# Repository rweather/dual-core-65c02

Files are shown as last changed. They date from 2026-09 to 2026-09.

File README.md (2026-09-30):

Dual Core 65C02 Computer
========================

This repository contains schematics, documentation, and program code for my
dual core 65C02 computer.  The computer has two 65C02 microprocessors,
sharing a common memory and I/O bus for symmetric multiprocessing (SMP),
8-bit style.

Here is what it looks like on a PCB.  The two large 40-pin chips at the
top are the CPU's.

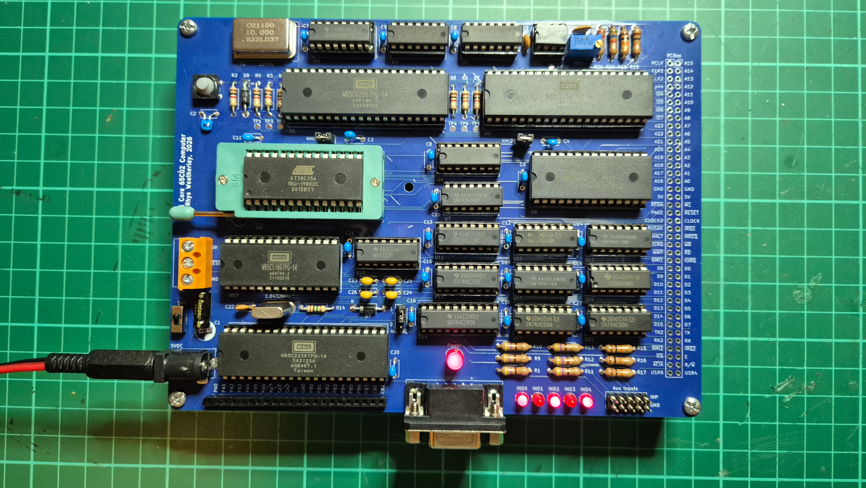
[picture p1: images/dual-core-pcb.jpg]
PCB Layout


If you would like to build your own, I have
[shared the design on PCBway](https://www.pcbway.com/project/shareproject/Dual_Core_65C02_Computer_47504aca.html).  Or contact me at the e-mail address
below and I might still have some spare PCB's I can mail out.

## How did this happen?

Steve Wozniak's design of the Apple II avoided video snow by alternating
access to main memory between the 6502 CPU and the video system.  The two
systems cannot collide and thus cannot create snow.

I asked myself, "Could I do that with two CPU's?" and an obsession was born.

## How does it work?

The W65C02S CPU from Western Digital simplifies things.  The BE
(bus enable) pin can be pulled low to take the CPU completely off the bus
temporarily.  By alternating the bus enables, each CPU can be given
access to memory and I/O in turn.

It would theoretically be possible to do this with the original 6502
microprocessor, but extra bus transceivers would be required as
the original 6502 does not have a BE pin.  The Apple II design
includes bus transceivers for exactly this purpose.

The main 12MHz crystal oscillator is divided down into a number of
component clock signals:

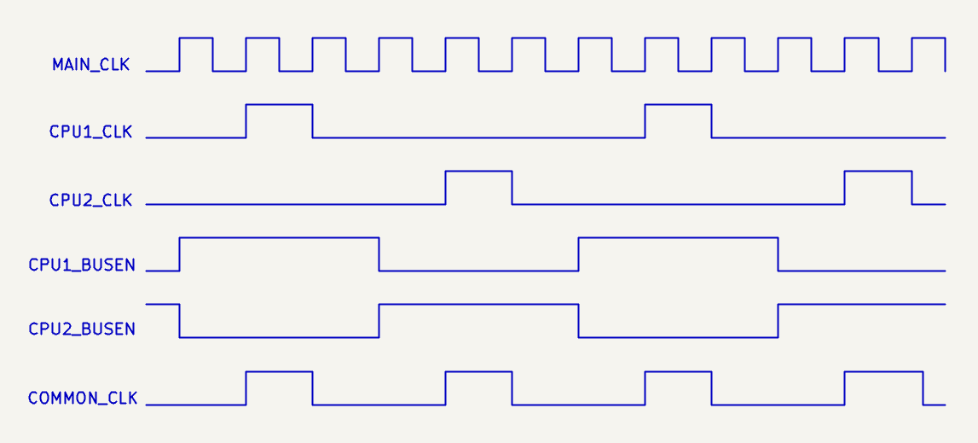
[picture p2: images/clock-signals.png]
Clock Signals


<table border="1">
<tr><td><b>Signal</b></td><td><b>Description</b></td></tr>
<tr><td>CPU1 CLK</td><td>2MHz clock for CPU1</td></tr>
<tr><td>CPU2 CLK</td><td>2MHz clock for CPU2</td></tr>
<tr><td>CPU1 BUSEN</td><td>2MHz bus enable for CPU1</td></tr>
<tr><td>CPU2 BUSEN</td><td>2MHz bus enable for CPU2</td></tr>
<tr><td>COMMON CLK</td><td>4MHz common clock for memory and I/O</td></tr>
</table>

## Memory map

<table border="1">
<tr><td><b>Address Range</b></td><td><b>Description</b></td></tr>
<tr><td>$0000 - $00FF</td><td>Zero page for CPU 1</td></tr>
<tr><td>$0100 - $01FF</td><td>Stack for CPU 1</td></tr>
<tr><td>$0200 - $02FF</td><td>Zero page for CPU 2</td></tr>
<tr><td>$0300 - $03FF</td><td>Stack for CPU 2</td></tr>
<tr><td>$0400 - $7FFF</td><td>Shared RAM (31K)</td></tr>
<tr><td>$8000 - $81FF</td><td>Main board I/O</td></tr>
<tr><td>$8200 - $83FF</td><td>Versatile Interface Adapter (VIA)</td></tr>
<tr><td>$8400 - $84FF</td><td>Asynchronous Communications Interface Adapter (ACIA)</td></tr>
<tr><td>$8600 - $87FF</td><td>RCbus I/O address space</td></tr>
<tr><td>$8800 - $8FFF</td><td>Spare I/O address space</td></tr>
<tr><td>$9000 - $BFFF</td><td>Unused memory space (12K)</td></tr>
<tr><td>$C000 - $FFFF</td><td>CPU-specific ROM (16K)</td></tr>
</table>

Address ranges $0000 - $01FF and $0200 - $03FF are swapped in CPU2 so that
CPU2 sees its zero page and stack starting at $0000 and sees CPU1's
zero page and stack starting at $0200.  This keeps the zero pages and
stacks separate.

The design uses a 32K EEPROM, divided into two 16K halves.  CPU1 sees
the first half of the ROM and CPU2 sees the second half of the ROM.
Thus, different programs can run on each CPU, or the same program.
It is up to the programmer.  This repository contains a minimal
[BIOS](src/common/bios.s) for initializing and accessing the hardware.

The main board decodes 8 I/O device address ranges between $8000 and $8FFF,
each consisting of 512 bytes ($0200 hex).  Four of these are used for
purposes on the main board.  The others are spare for expansion boards.

The 12K of unused memory space can be used for bank-switched RAM, video
memory, cartridge ROM's, or anything you want.

## Mutual exclusion

In any multi-core system, some method is required to synchronise access to
memory and I/O across the cores.  The 65C02 takes multiple clock cycles to
perform a read-modify-write instruction like "INC" or "DEC".  The other core
could get in the middle of that and mess things up.

According to the W65C02S datasheet, the ML pin can be used to co-ordinate
bus accesses when read-modify-write instructions are being performed.
I experimented with a method to "stretch" the bus enable signals to
delay the other CPU while the current one was performing a read-modify-write.
But I wasn't able to make it stable.

Instead, I use two flip-flops and some I/O pins to provide mutual exclusion.
In Logisim, it looks like this:

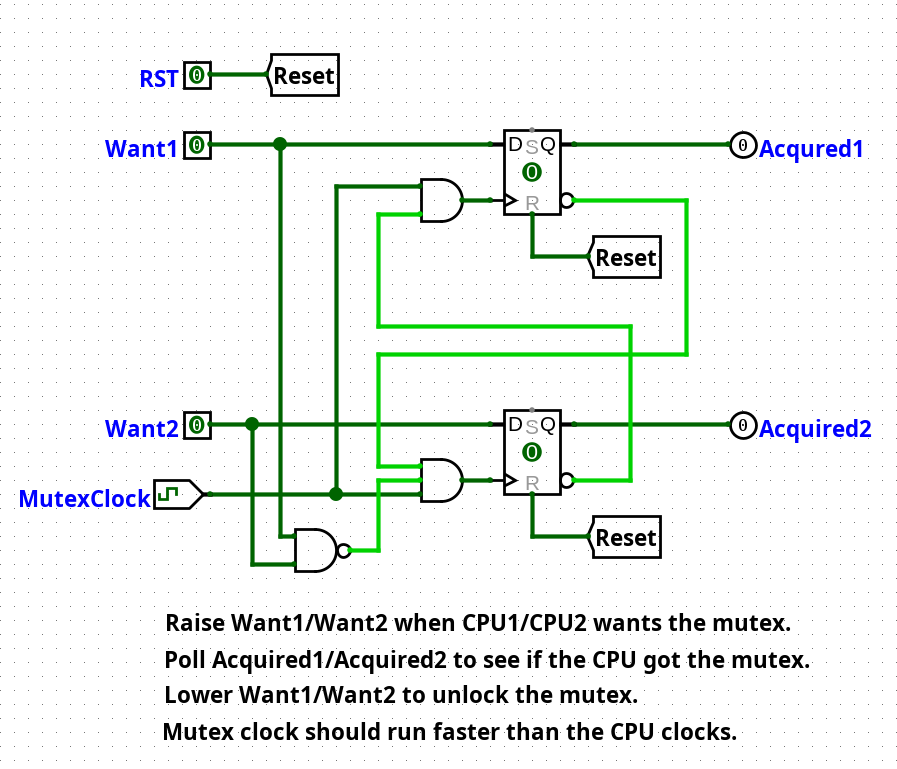
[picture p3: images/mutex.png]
Mutual exclusion


When CPU1 wants the mutex, it raises the Want1 pin (address $8107, bit 0) and
then polls the Acquired1 signal (address $8080, bit 7).  Once the acquired
signal goes high, CPU1 has the mutex.  To release the mutex, lower the
Want1 pin.

CPU2 does the same thing with Want2 (address $8106, bit 0) and
Acquired2 (address $8080, bit 6).

The mutex is "fair" in the sense that when one CPU lowers its Want pin,
the other CPU is guaranteed to immediately get the mutex if it had
previously raised its Want pin.  It is impossible for one CPU to
hog the mutex, except by forgetting to unlock it.

The [BIOS](src/common/bios.s) provides the subroutines `mutex_lock`,
`mutex_unlock`, and `mutex_try_lock` to make things easier for the
programmer.  The implementation is different for each CPU.

## System millisecond tick timer

There is a 555 timer in the circuit that delivers a 1000Hz signal to the
NMI pins on each of the CPU's.  A potentiometer allows the frequency to
be dialed in precisely.

The default NMI handler in the BIOS increments a 24-bit millisecond
tick counter which wraps around after 4 hours and 39 minutes.
Call the `systick` subroutine to fetch the value of the tick counter
safely into the Y:X:A register triple.

NMI can interfere with foreground code and regular IRQ handlers,
which may affect timing-critical code.  There are jumpers in the circuit
that allow the 555 to be disconnected from one or both of the CPU's.

## Schematic and other technical information

* [PDF of the schematic](schematics/DualCore6502Whole/PDF/DualCore6502Whole.pdf)
* [Gerbers for the PCB](schematics/DualCore6502Whole/Gerber)
* [Parts list](doc/parts-list.md)

## What can't it do?

DMA is not currently supported.  Pausing the clocks and bus enables to allow
external access to the bus is complicated.  Too complicated for my feeble brain.
Maybe in the next version.

In theory the W65C02S can go up to 14MHz.  While SRAM that is faster than
70ns access time is possible, AT28C256 EEPROM chips form are typically 150ns.
In practice, this limits the maximum memory speed to about 4MHz.
AT27C256 EEPROM's can go down to 45ns but they are not pin-compatible and
that still only gets us to 8MHz or so.  An alternative memory design with
wait states may allow pushing the performance further.  Once again,
my feeble brain isn't up to the task.

Could we have more CPU's?  Four?  Eight?  In theory, yes.  But memory
access times limit things.  The speed of the individual CPU's would need to be
reduced to 1MHz to allow four on the bus, executing one after another.
The effective speed of the system would remain at 4MHz.  An alternate design
might give each CPU its own fast SRAM, with wait states for access to
common RAM, ROM, and I/O.

## TODO

* Machine monitor for loading programs into RAM via the serial port and
debugging them (partially done).
* Devise a multi-core operating system to showcase the capabilities.

## License

Distributed under the terms of the MIT license.

## Contact

For more information on this code, to report bugs, or to suggest
improvements, please contact the author Rhys Weatherley via
[email](mailto:rhys.weatherley@gmail.com).

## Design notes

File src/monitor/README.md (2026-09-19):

This directory contains a machine monitor for the Dual Core 65C02 Computer.

The name of the monitor is "Maggot MON", which is the name I used for my
replacement machine monitor projects for the Dick Smith Cat in the 1980's.
I was 15 years old!

Maggot MON has evolved over the years into a replacement for the
Apple II F8 ROM for use with homebrew 6502 computers.  Now with ANSI
colour codes over a TTY, support for lower case, improved assembler and
disassembler, and so on.

On a dual core system, the monitor runs in CPU1.

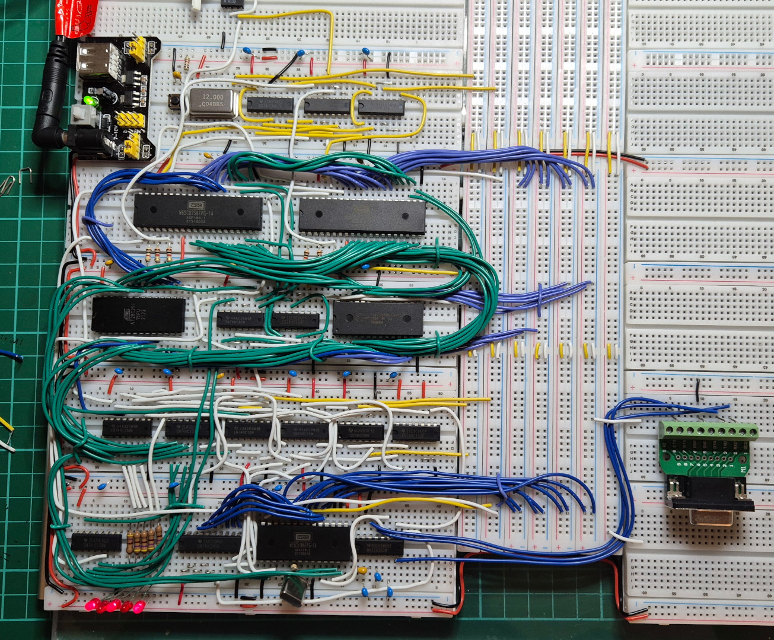
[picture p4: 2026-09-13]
images/dual-core-breadboard.jpg

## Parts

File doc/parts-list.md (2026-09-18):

Parts list for Dual Core 65C02
==============================

## Integrated Circuits

* 2 x W65C02S 8-bit microprocessor
* 1 x W65C22N versatile interface adapter (VIA)
* 1 x W65C51N asynchronous communications interface adapter (ACIA)
* 1 x 62256 32K x 8 static RAM, 70ns or better access time
* 1 x 28C256 32K x 8 EEPROM, 150ns or better access time
* 1 x MAX232 RS-232 line driver
* 1 x 7555 CMOS timer
* 3 x 74HC00 quad 2-input NAND gate
* 1 x 74HC02 quad 2-input NOR gate
* 1 x 74HC08 quad 2-input AND gate
* 1 x 74HC10 triple 3-input NAND gate
* 1 x 74HC32 quad 2-input OR gate
* 1 x 74HC74 dual D flip-flop
* 1 x 74HC86 quad 2-input XOR gate
* 2 x 74HC138 1 of 8 decoder
* 1 x 74HC245 8-bit bus transceiver
* 1 x 74HC259 8-bit addressable latch
* 1 x 74HC4017 decade counter

## Resistors

* 6 x 470R resistor
* 7 x 1K resistor
* 1 x 2K2 resistor
* 1 x 5K6 resistor
* 5 x 10K resistor
* 1 x 1M resistor
* 1 x 10K trimpot

Note: All resistors should be rated for at least 5% tolerance and 1/4W.

## Capacitors

* 1 x 100uF electroltic capacitor, min 10V rating
* 4 x 1uF ceramic or monolithic capacitor
* 22 x 100nF ceramic or monolithic capacitor
* 1 x 10nF ceramic or monolithic capacitor
* 1 x 20pF ceramic capacitor

## Diodes and LED's

* 2 x 1N5819 Schottky diodes or equivalent
* 1 x 5mm LED
* 5 x 3mm LED

Note: The current-limiting resistors for the LED's are specified as 470R
which is suitable for standard 10mA to 20mA LED's.  Adjust the value of the
current limiting resistors for other LED's.

## Sockets, Recommended

* 3 x 40-pin DIP socket (2 x W65C02S, 1 x W65C22N)
* 2 x 28-pin DIP socket (1 x 62256, 1 x W65C51N)
* 1 x 28-pin ZIF socket (1 x 28C256)

## Sockets, Optional

* 1 x 8-pin DIP socket
* 9 x 14-pin DIP socket
* 5 x 16-pin DIP socket
* 1 x 20-pin DIP socket

## Connectors and Headers

* 1 x DC barrel jack
* 1 x DSUB 9-pin RS-232 connector female
* 1 x 3-pin Phoenix connector or 3-pin 5.08mm pitch screw terminals
* 1 x 3-pin 2.54mm terminal pin header
* 2 x 2-pin 2.54mm terminal pin header
* 1 x 10-pin 2.54mm terminal pin header, 5x2 configuration
* 1 x 22-pin 2.54mm terminal pin socket
* 1 x 80-pin 2.54mm terminal pin socket, 40x2 configuration
* 8 x 2-pin 2.54mm jumper (NMI1, NMI2, VIA IRQ, and 5 Aux Inputs)

## Other

* 1 x 12MHz DIP-14 crystal oscillator
* 1 x 1.8432MHz crystal
* 1 x 3-pin 2.54mm pitch slider switch for power
* 1 x 6mm momentary pushbutton for reset
* 1 x PCB

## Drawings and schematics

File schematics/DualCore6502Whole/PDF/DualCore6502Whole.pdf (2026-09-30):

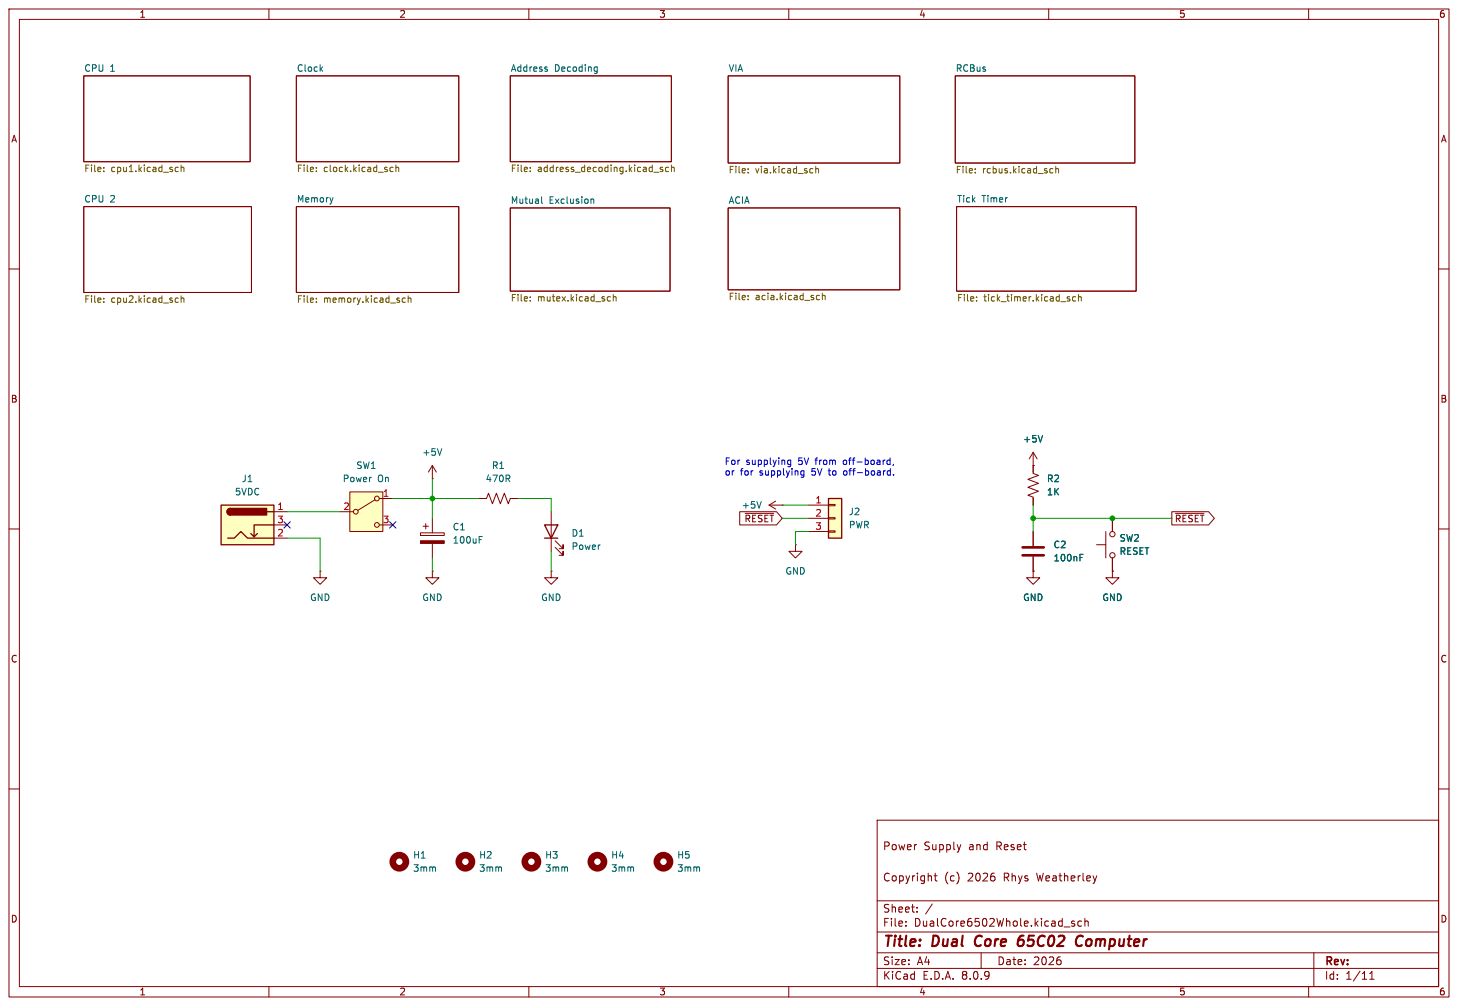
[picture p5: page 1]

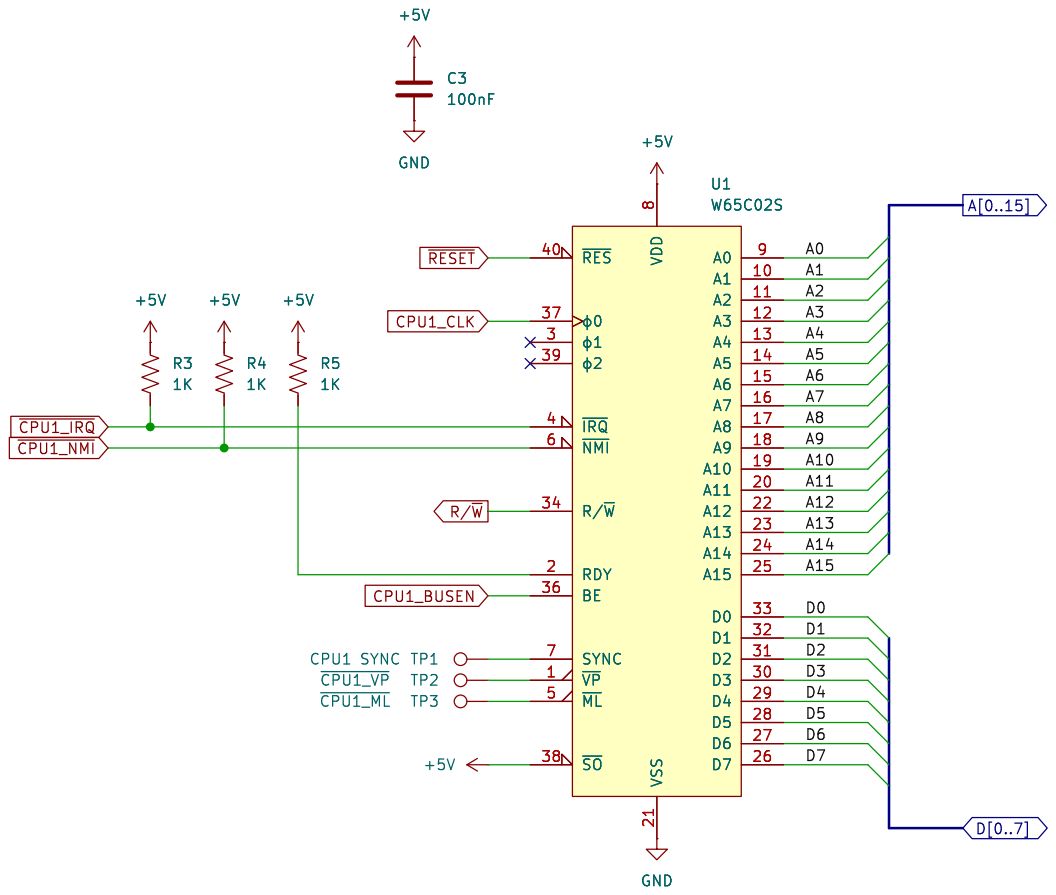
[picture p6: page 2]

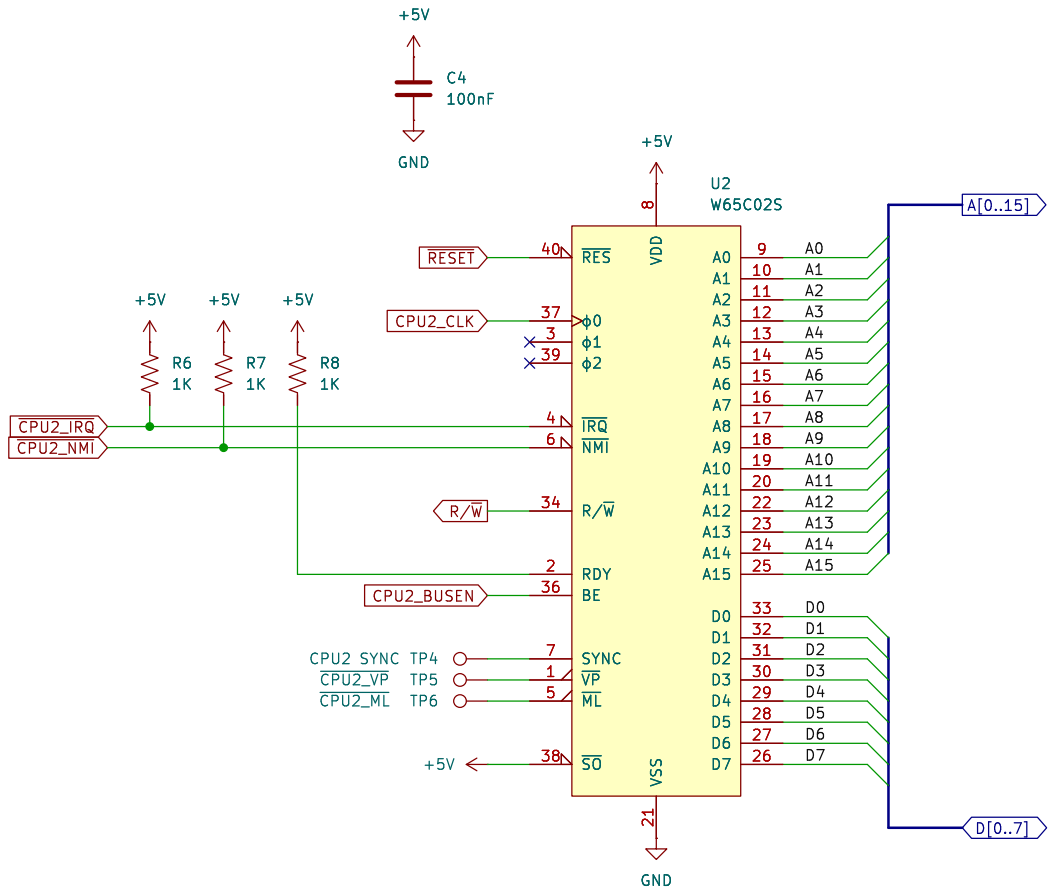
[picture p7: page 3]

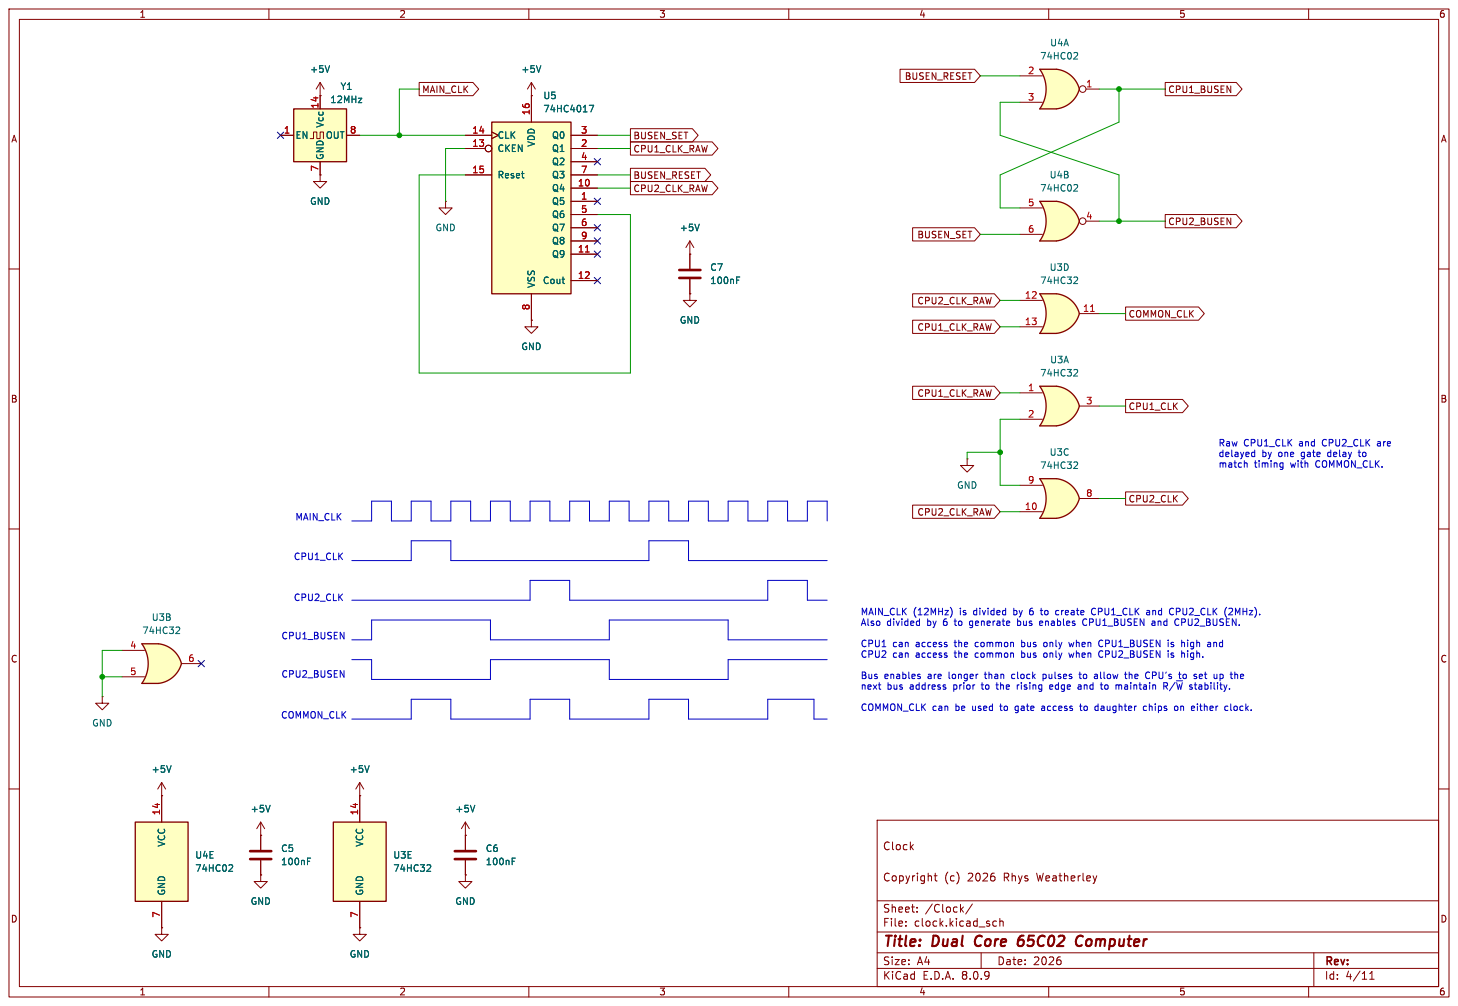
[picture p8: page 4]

delayed by one gate delay to match timing with COMMON_CLK. CPU2_BUSEN

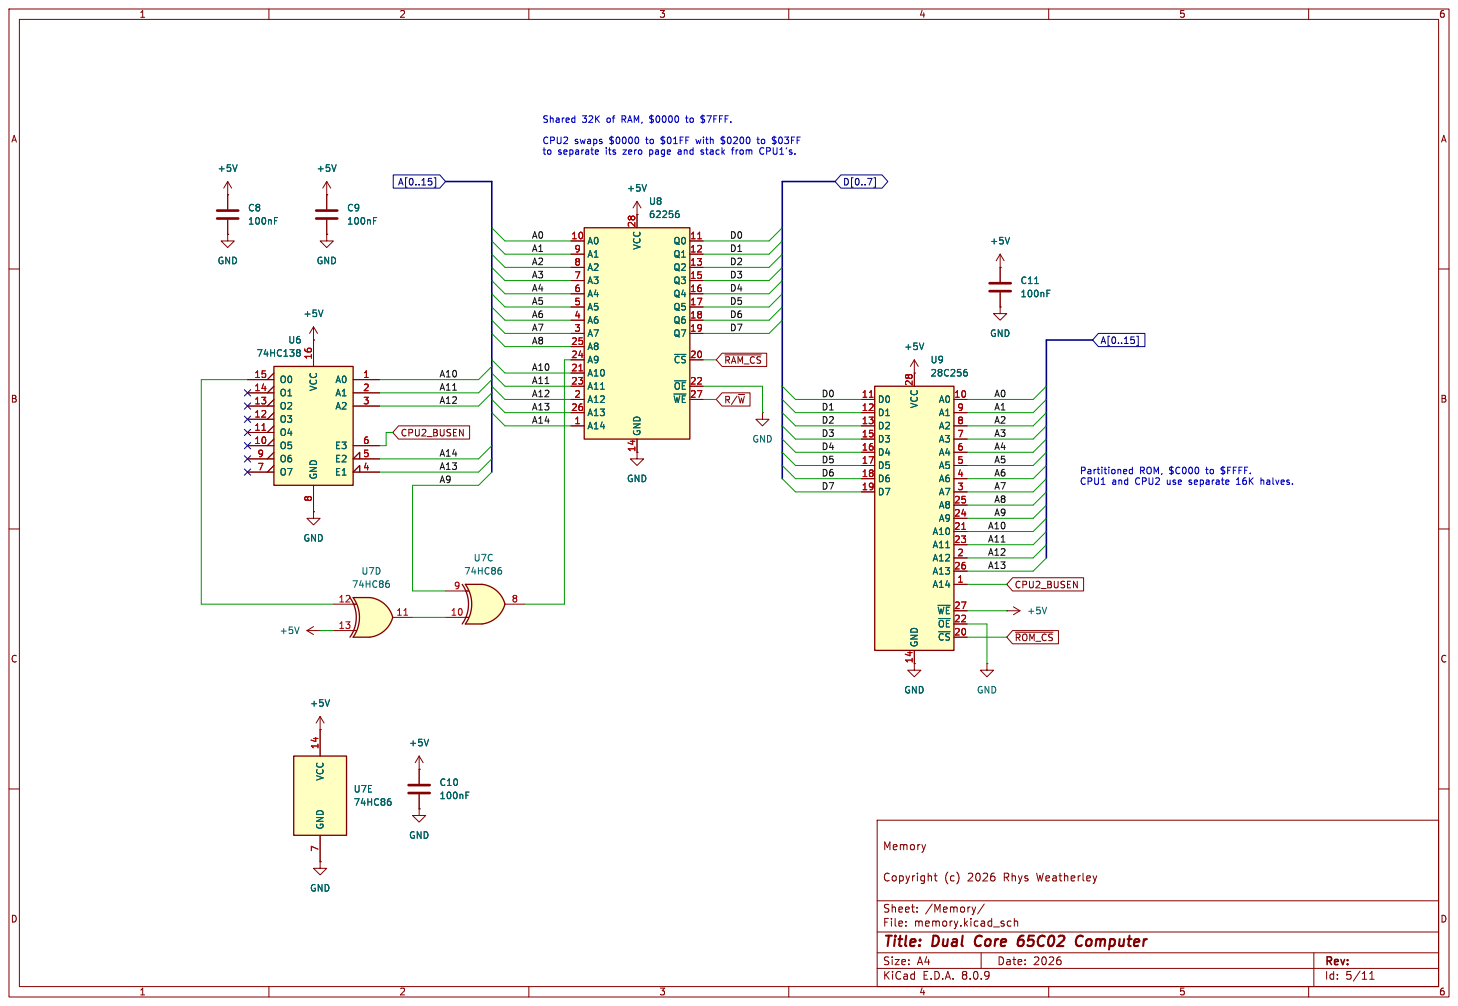
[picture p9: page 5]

Id: 5/11 Title: Dual Core 65C02 Computer File: memory.kicad_sch Sheet: /Memory/

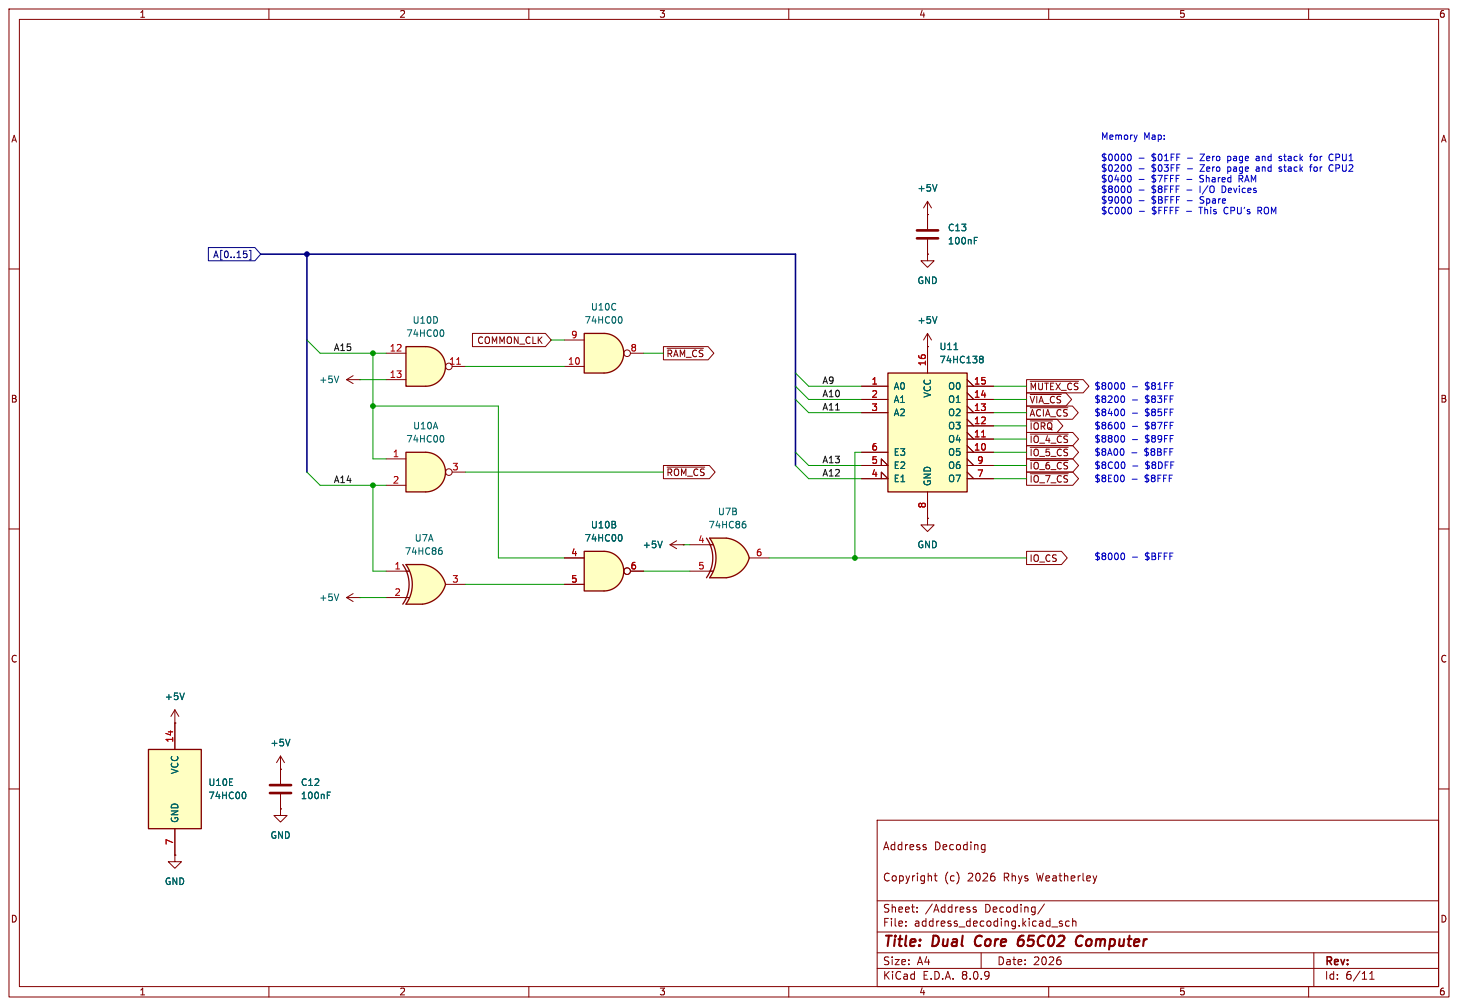
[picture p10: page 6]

$0200 - $03FF - Zero page and stack for CPU2
$0400 - $7FFF - Shared RAM
$8000 - $8FFF - I/O Devices $9000 - $BFFF - Spare

$C000 - $FFFF - This CPU's ROM

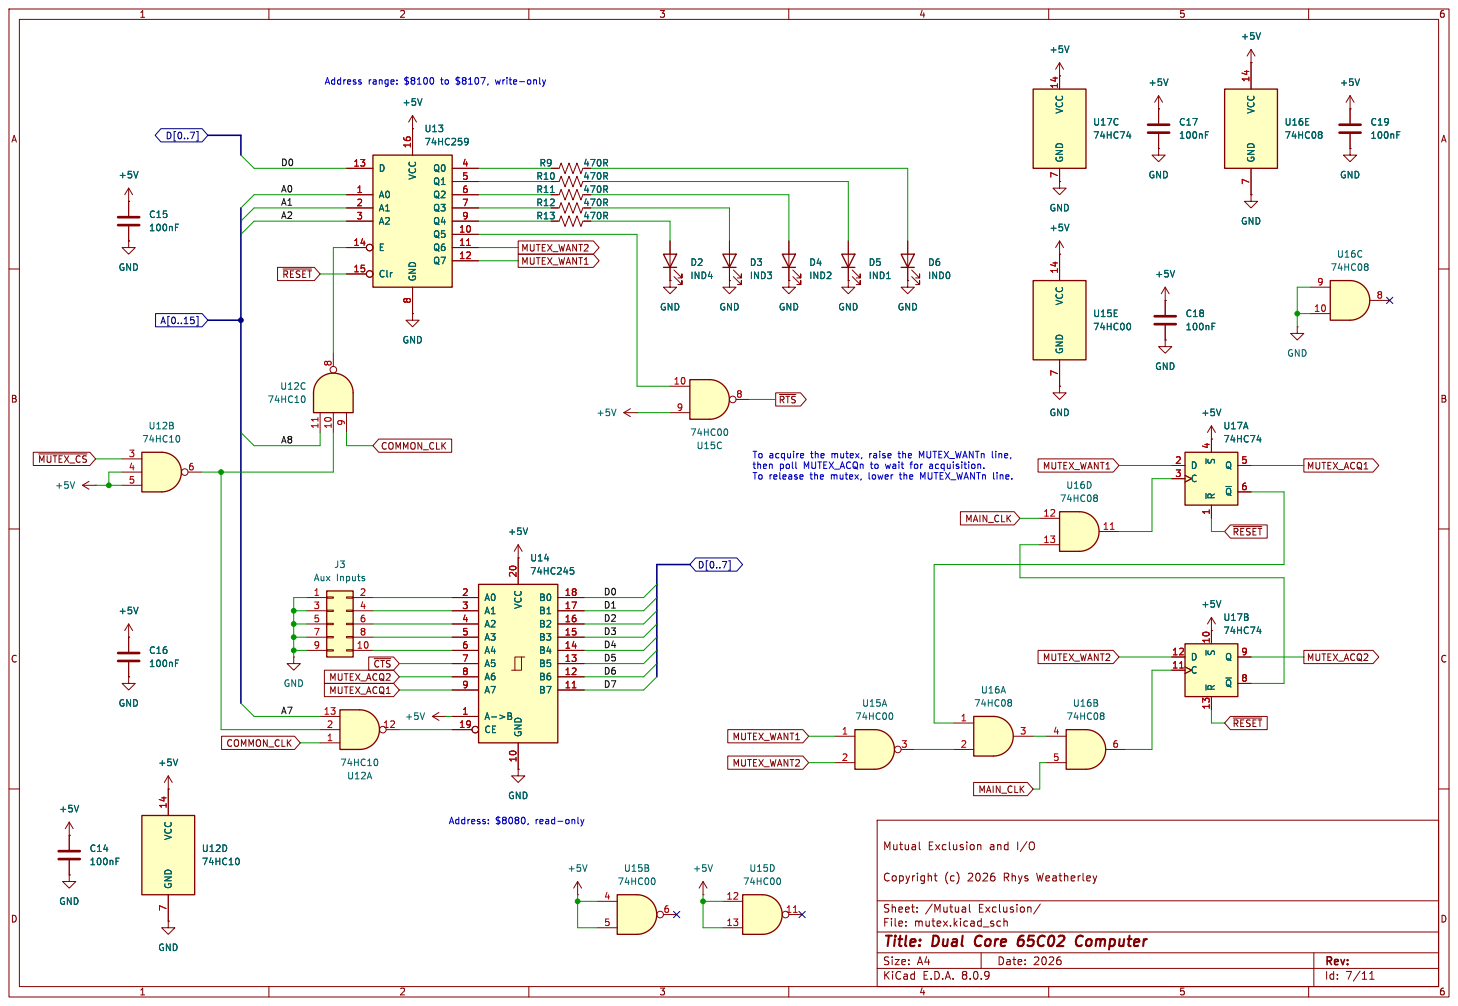
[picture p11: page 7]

then poll MUTEX_ACQn to wait for acquisition. To release the mutex, lower the MUTEX_WANTn line. Address range: $8100 to $8107, write-only

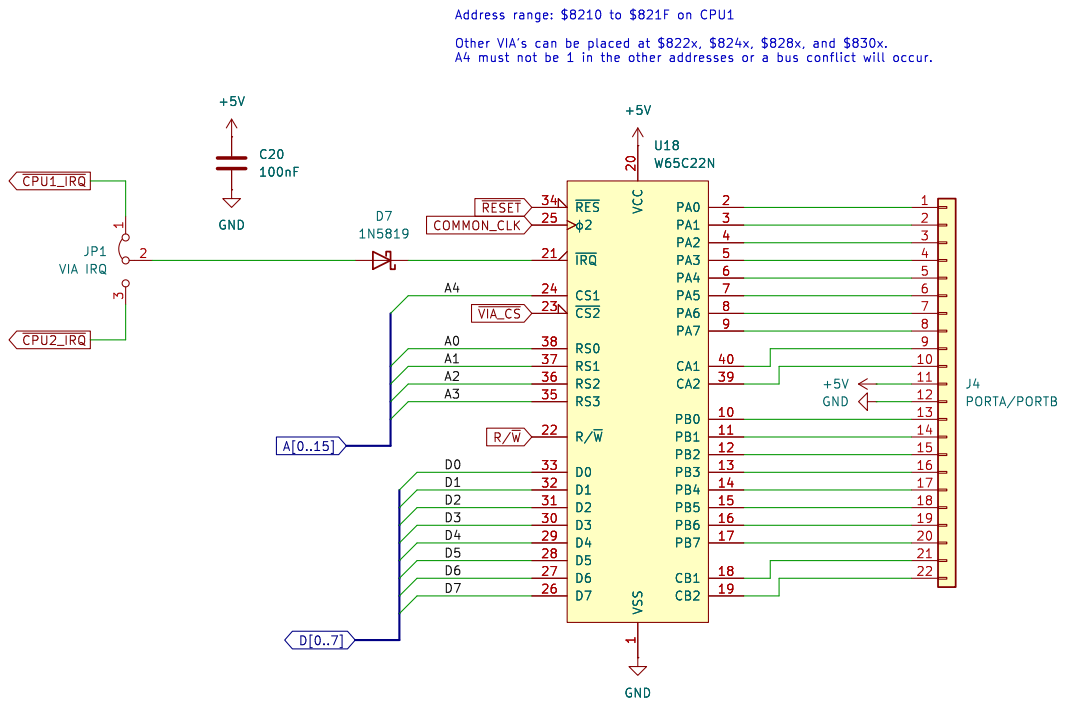
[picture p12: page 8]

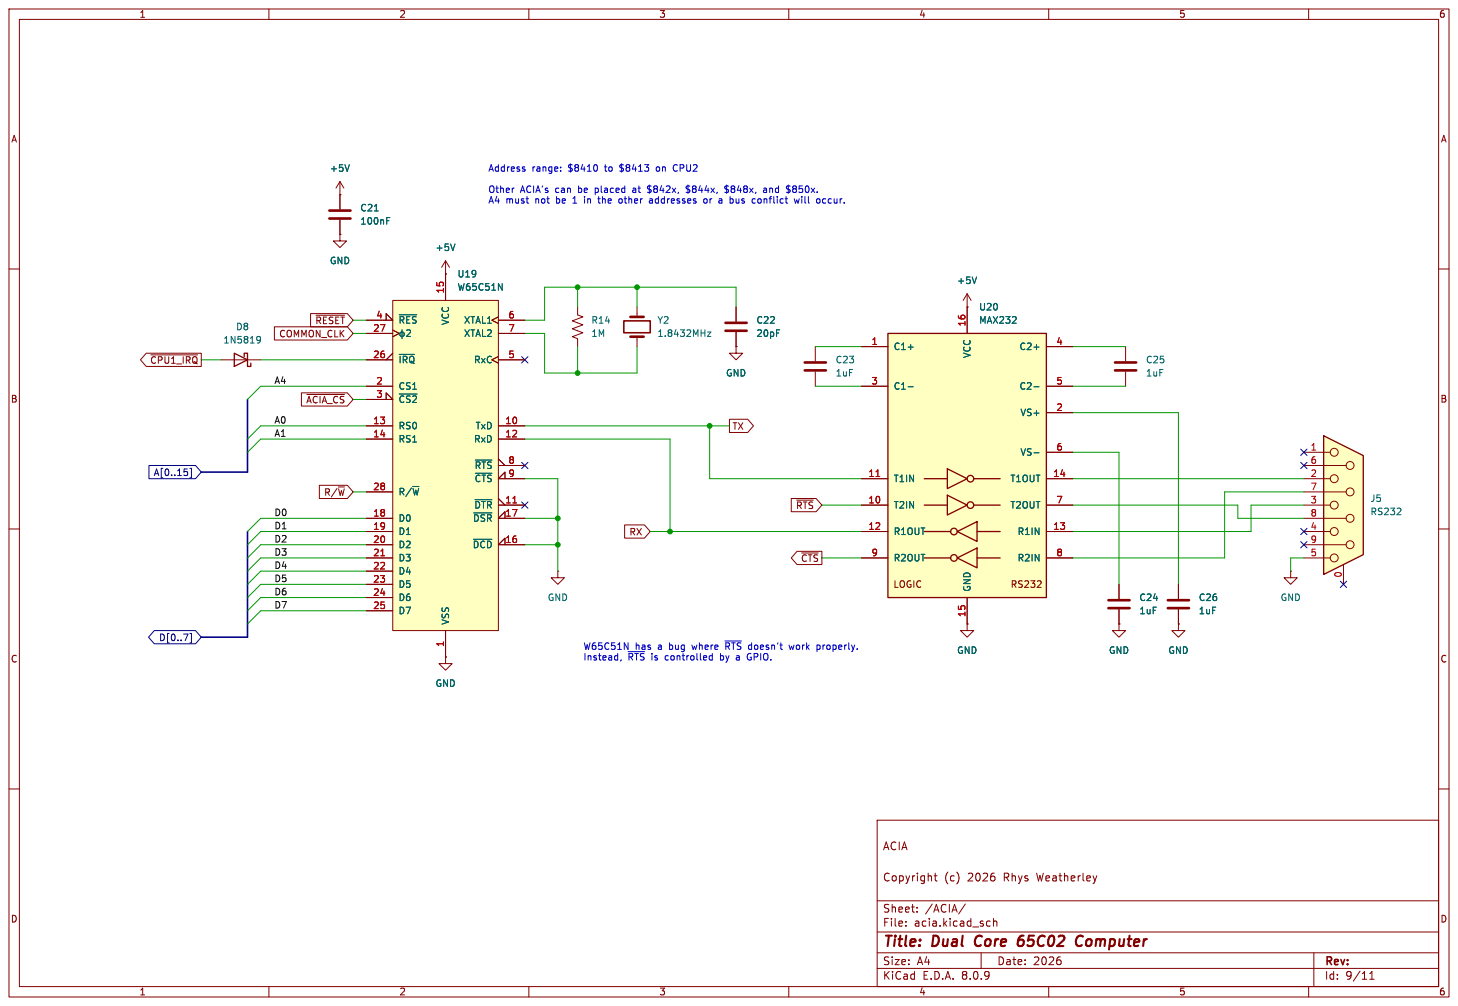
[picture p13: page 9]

1 TxD 10 ~{DTR}11 RxD 12 RS0 13 RS1 14 VCC 15

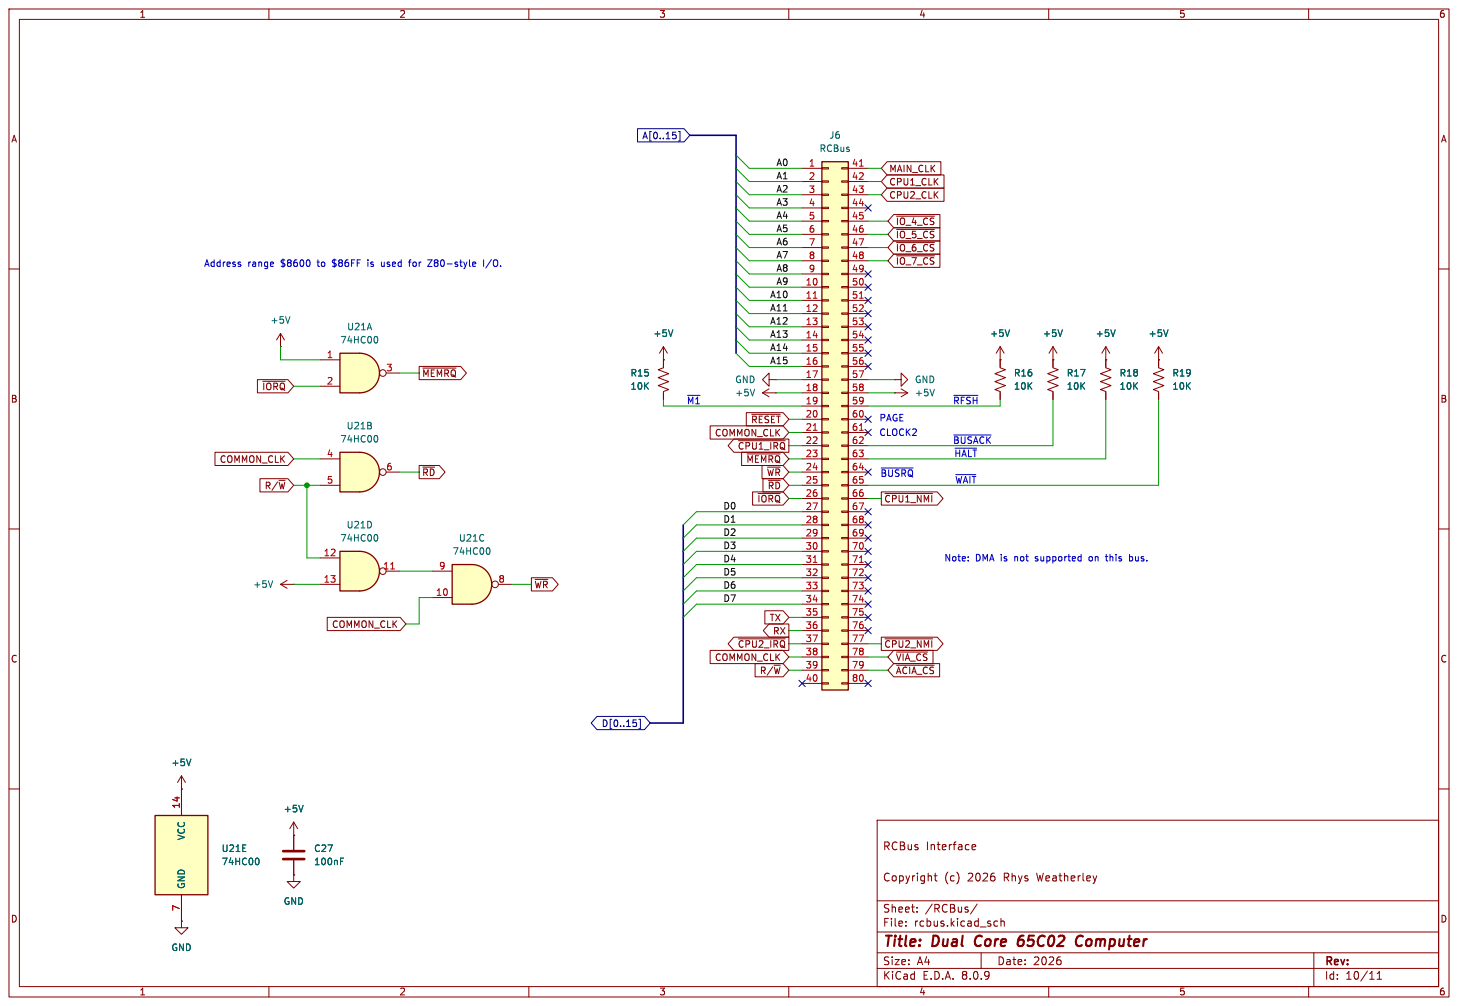
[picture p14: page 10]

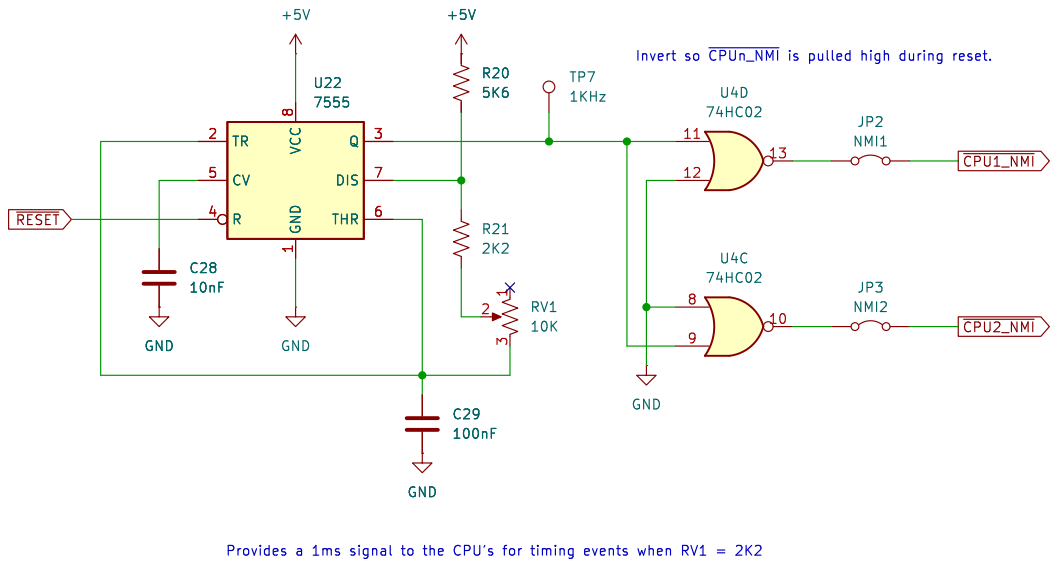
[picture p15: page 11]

Invert so ~{CPUn_NMI}is pulled high during reset. Provides a 1ms signal to the CPU's for timing events when RV1 = 2K2 U22

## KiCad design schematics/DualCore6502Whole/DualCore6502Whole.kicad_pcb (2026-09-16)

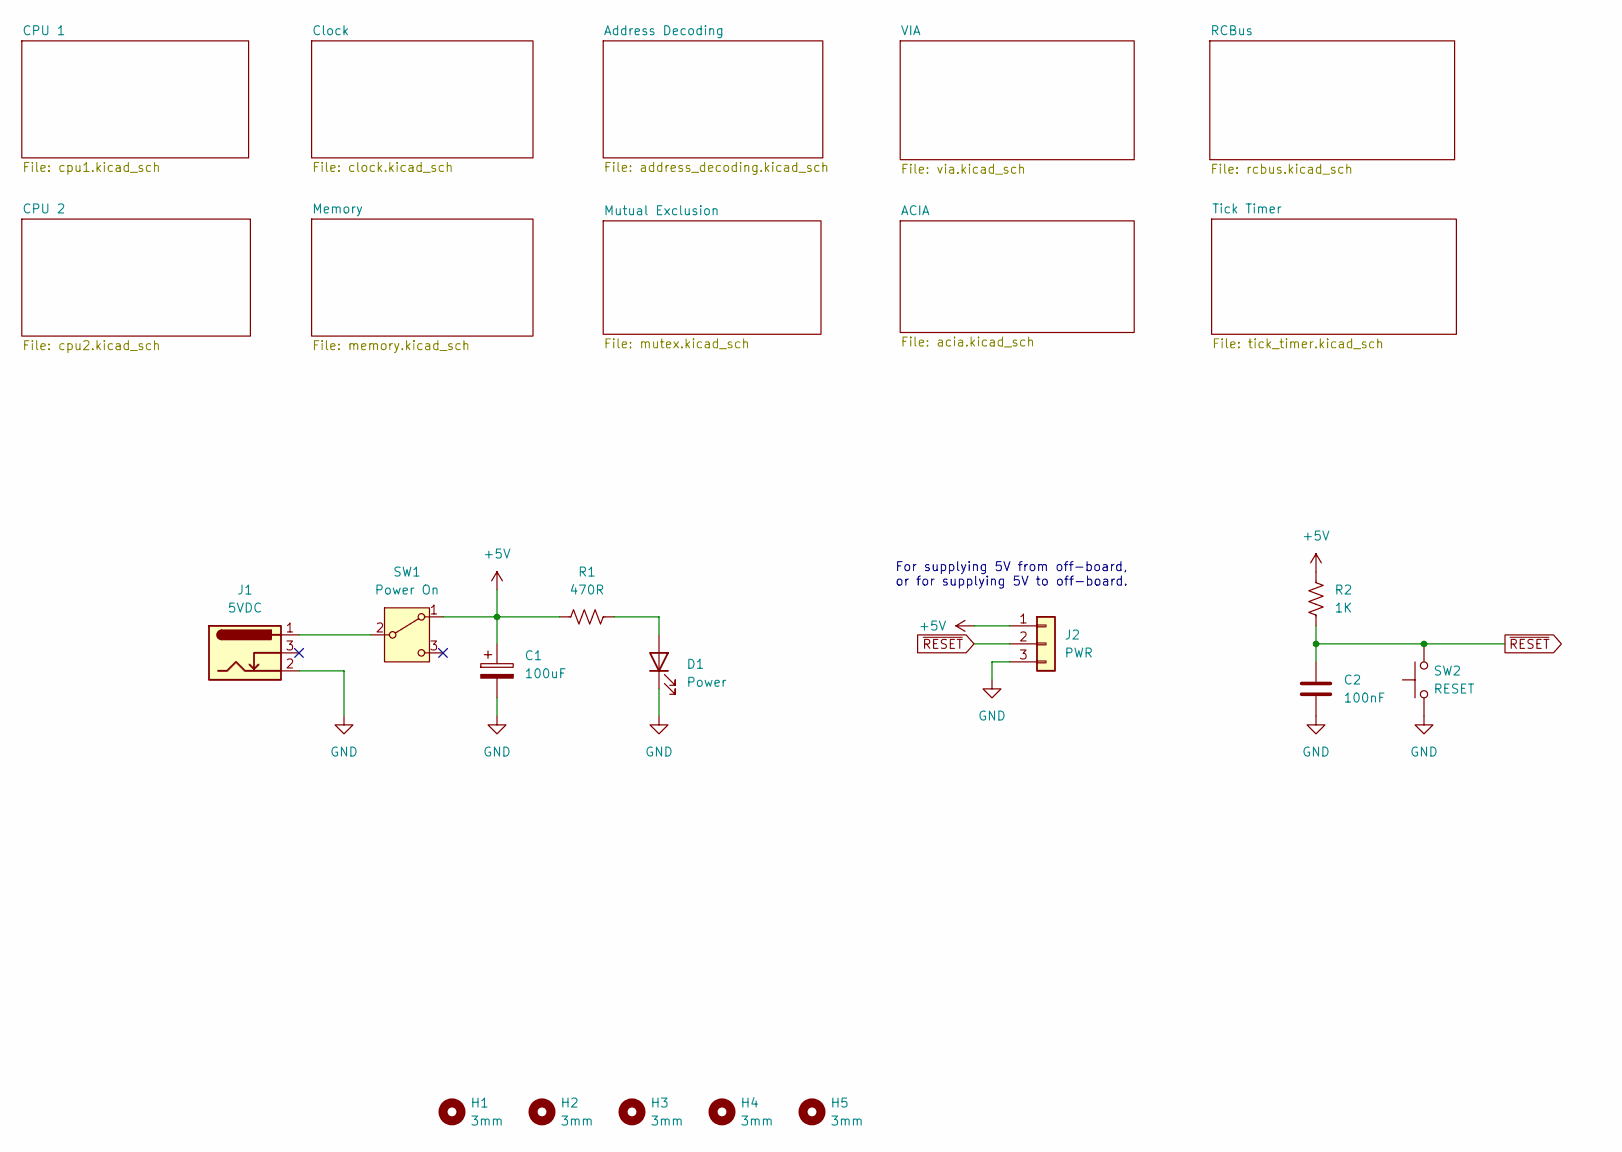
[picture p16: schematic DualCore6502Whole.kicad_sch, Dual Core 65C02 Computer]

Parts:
C1: 100uF; CP_Radial_D6.3mm_P2.50mm
C2: 100nF; C_Disc_D5.0mm_W2.5mm_P5.00mm
D1: Power; LED_D5.0mm
H1, H2, H3, H4, H5: 3mm; MountingHole_3mm
J1: 5VDC; BarrelJack_Horizontal
J2: PWR; PhoenixContact_MC_1,5_3-G-5.08_1x03_P5.08mm_Horizontal
R1: 470R; R_Axial_DIN0207_L6.3mm_D2.5mm_P10.16mm_Horizontal
R2: 1K; R_Axial_DIN0207_L6.3mm_D2.5mm_P10.16mm_Horizontal
SW1: Power On; PinHeader_1x03_P2.54mm_Vertical
SW2: RESET; SW_PUSH_6mm_H5mm

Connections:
+5V: C1.1, J2.1, R1.1, R2.1, SW1.1 (A); also elsewhere on the board
GND: C1.2, C2.2, D1.1 (K), J1.2, J2.3, SW2.1; also elsewhere on the board
unnamed: D1.2 (A), R1.2
unnamed: J1.1, SW1.2 (B)
~RESET: C2.1, J2.2, R2.2, SW2.2; also elsewhere on the board

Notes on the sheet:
For supplying 5V from off-board, or for supplying 5V to off-board.

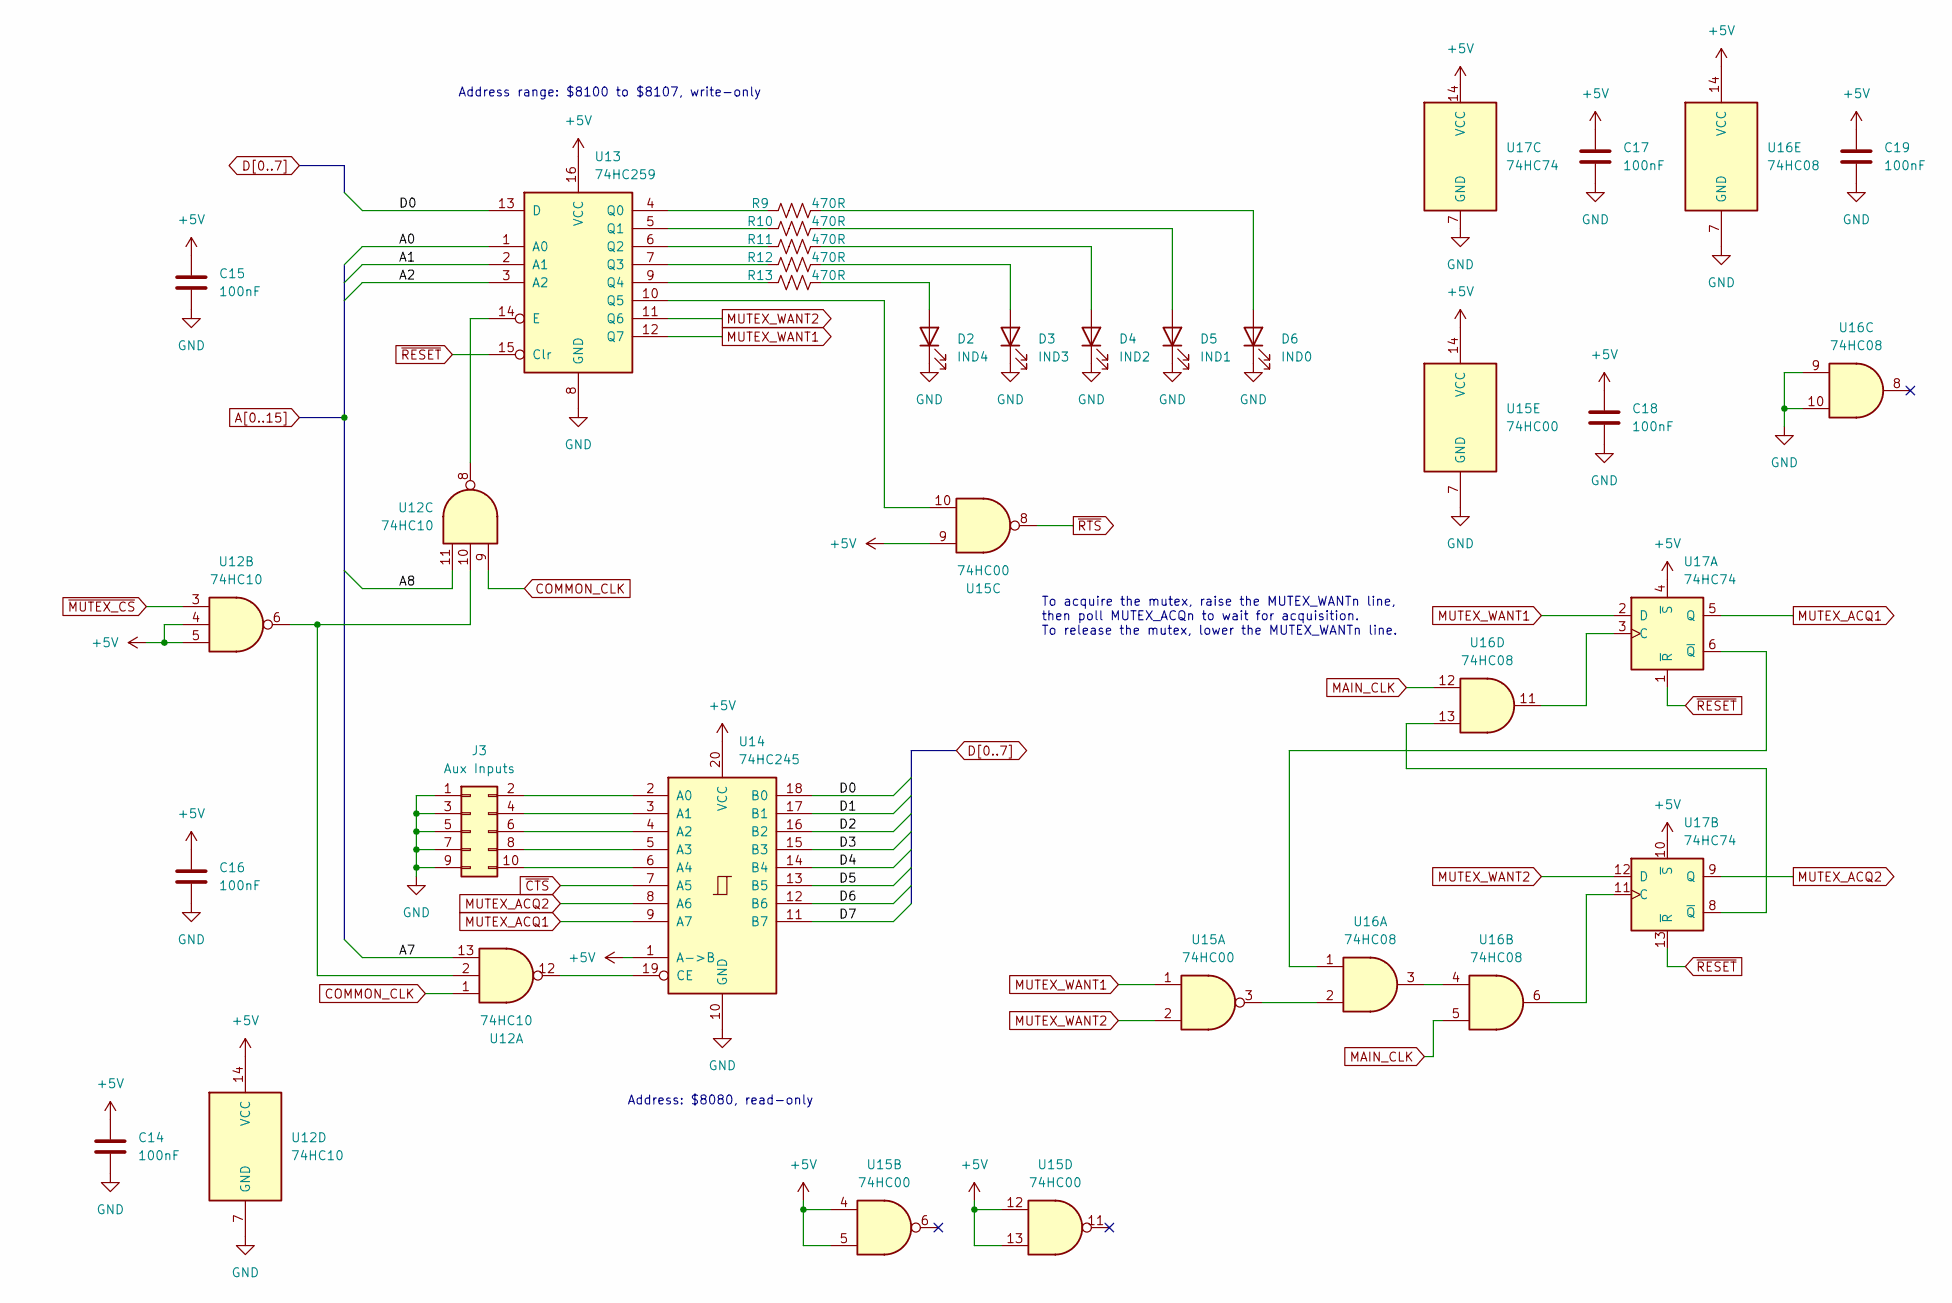
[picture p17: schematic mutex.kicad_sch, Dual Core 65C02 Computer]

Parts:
C14, C15, C16, C17, C18, C19: 100nF; C_Disc_D5.0mm_W2.5mm_P5.00mm
D2: IND4; LED_D3.0mm
D3: IND3; LED_D3.0mm
D4: IND2; LED_D3.0mm
D5: IND1; LED_D3.0mm
D6: IND0; LED_D3.0mm
J3: Aux Inputs; PinHeader_2x05_P2.54mm_Vertical
R9, R10, R11, R12, R13: 470R; R_Axial_DIN0207_L6.3mm_D2.5mm_P10.16mm_Horizontal
U12: 74HC10; DIP-14_W7.62mm_Socket
U13: 74HC259; DIP-16_W7.62mm_Socket
U14: 74HC245; DIP-20_W7.62mm_Socket
U15: 74HC00; DIP-14_W7.62mm_Socket
U16: 74HC08; DIP-14_W7.62mm_Socket
U17: 74HC74; DIP-14_W7.62mm_Socket

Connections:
+5V: C14.1, C15.1, C16.1, C17.1, C18.1, C19.1, U12.4, U12.5, U12.14 (VCC), U13.16 (VCC), U14.1 (A->B), U14.20 (VCC), U15.4, U15.5, U15.9, U15.12, U15.13, U15.14 (VCC), U16.14 (VCC), U17.4 (~S), U17.10 (~S), U17.14 (VCC); also elsewhere on the board
A0: U13.1 (A0); also elsewhere on the board
A1: U13.2 (A1); also elsewhere on the board
A2: U13.3 (A2); also elsewhere on the board
A7: U12.13; also elsewhere on the board
A8: U12.11; also elsewhere on the board
COMMON_CLK: U12.1, U12.9; also elsewhere on the board
D0: U13.13 (D), U14.18 (B0); also elsewhere on the board
D1: U14.17 (B1); also elsewhere on the board
D2: U14.16 (B2); also elsewhere on the board
D3: U14.15 (B3); also elsewhere on the board
D4: U14.14 (B4); also elsewhere on the board
D5: U14.13 (B5); also elsewhere on the board
D6: U14.12 (B6); also elsewhere on the board
D7: U14.11 (B7); also elsewhere on the board
GND: C14.2, C15.2, C16.2, C17.2, C18.2, C19.2, D2.1 (K), D3.1 (K), D4.1 (K), D5.1 (K), D6.1 (K), J3.1, J3.3, J3.5, J3.7, J3.9, U12.7 (GND), U13.8 (GND), U14.10 (GND), U15.7 (GND), U16.7 (GND), U16.9, U16.10, U17.7 (GND); also elsewhere on the board
MAIN_CLK: U16.5, U16.12; also elsewhere on the board
MUTEX_ACQ1: U14.9 (A7), U17.5 (Q)
MUTEX_ACQ2: U14.8 (A6), U17.9 (Q)
MUTEX_WANT1: U13.12 (Q7), U15.1, U17.2 (D)
MUTEX_WANT2: U13.11 (Q6), U15.2, U17.12 (D)
unnamed: D2.2 (A), R13.2
unnamed: D3.2 (A), R12.2
unnamed: D4.2 (A), R11.2
unnamed: D5.2 (A), R10.2
unnamed: D6.2 (A), R9.2
unnamed: J3.2, U14.2 (A0)
unnamed: J3.4, U14.3 (A1)
unnamed: J3.6, U14.4 (A2)
unnamed: J3.8, U14.5 (A3)
unnamed: J3.10, U14.6 (A4)
unnamed: U12.2, U12.6, U12.10
unnamed: U12.8, U13.14 (E)
unnamed: R9.1, U13.4 (Q0)
unnamed: R10.1, U13.5 (Q1)
unnamed: R11.1, U13.6 (Q2)
unnamed: R12.1, U13.7 (Q3)
unnamed: R13.1, U13.9 (Q4)
unnamed: U13.10 (Q5), U15.10
unnamed: U12.12, U14.19 (CE)
unnamed: U15.3, U16.2
unnamed: U16.3, U16.4
unnamed: U16.11, U17.3 (C)
unnamed: U16.1, U17.6 (~Q)
unnamed: U16.6, U17.11 (C)
unnamed: U16.13, U17.8 (~Q)
~CTS: U14.7 (A5); also elsewhere on the board
~MUTEX_CS: U12.3; also elsewhere on the board
~RESET: U13.15 (Clr), U17.1 (~R), U17.13 (~R); also elsewhere on the board
~RTS: U15.8; also elsewhere on the board

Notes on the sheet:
Address range: $8100 to $8107, write-only
Address: $8080, read-only
To acquire the mutex, raise the MUTEX_WANTn line, then poll MUTEX_ACQn to wait for acquisition. To release the mutex, lower the MUTEX_WANTn line.

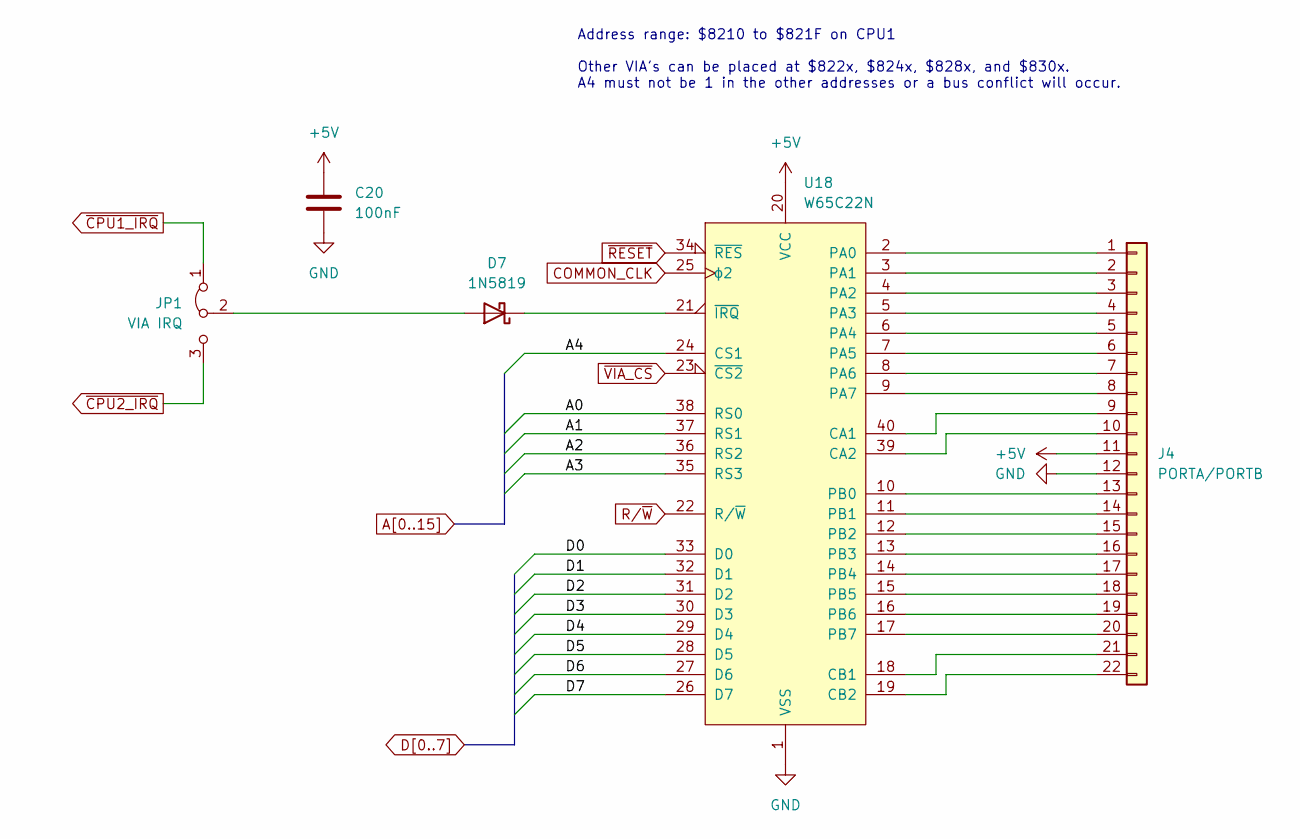
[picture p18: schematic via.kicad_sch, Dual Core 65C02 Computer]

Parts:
C20: 100nF; C_Disc_D5.0mm_W2.5mm_P5.00mm
D7: 1N5819; D_DO-41_SOD81_P10.16mm_Horizontal
J4: PORTA/PORTB; PinSocket_1x22_P2.54mm_Vertical
JP1: VIA IRQ; PinHeader_1x03_P2.54mm_Vertical
U18: W65C22N; DIP-40_W15.24mm_Socket

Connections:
+5V: C20.1, J4.11, U18.20 (VCC); also elsewhere on the board
A0: U18.38 (RS0); also elsewhere on the board
A1: U18.37 (RS1); also elsewhere on the board
A2: U18.36 (RS2); also elsewhere on the board
A3: U18.35 (RS3); also elsewhere on the board
A4: U18.24 (CS1); also elsewhere on the board
COMMON_CLK: U18.25 (ϕ2); also elsewhere on the board
D0: U18.33 (D0); also elsewhere on the board
D1: U18.32 (D1); also elsewhere on the board
D2: U18.31 (D2); also elsewhere on the board
D3: U18.30 (D3); also elsewhere on the board
D4: U18.29 (D4); also elsewhere on the board
D5: U18.28 (D5); also elsewhere on the board
D6: U18.27 (D6); also elsewhere on the board
D7: U18.26 (D7); also elsewhere on the board
GND: C20.2, J4.12, U18.1 (VSS); also elsewhere on the board
unnamed: D7.2 (A), JP1.2 (C)
unnamed: D7.1 (K), U18.21 (~IRQ)
unnamed: J4.1, U18.2 (PA0)
unnamed: J4.2, U18.3 (PA1)
unnamed: J4.3, U18.4 (PA2)
unnamed: J4.4, U18.5 (PA3)
unnamed: J4.5, U18.6 (PA4)
unnamed: J4.6, U18.7 (PA5)
unnamed: J4.7, U18.8 (PA6)
unnamed: J4.8, U18.9 (PA7)
unnamed: J4.9, U18.40 (CA1)
unnamed: J4.10, U18.39 (CA2)
unnamed: J4.13, U18.10 (PB0)
unnamed: J4.14, U18.11 (PB1)
unnamed: J4.15, U18.12 (PB2)
unnamed: J4.16, U18.13 (PB3)
unnamed: J4.17, U18.14 (PB4)
unnamed: J4.18, U18.15 (PB5)
unnamed: J4.19, U18.16 (PB6)
unnamed: J4.20, U18.17 (PB7)
unnamed: J4.21, U18.18 (CB1)
unnamed: J4.22, U18.19 (CB2)
R/~W: U18.22 (R/~W); also elsewhere on the board
~CPU1_IRQ: JP1.1 (A); also elsewhere on the board
~CPU2_IRQ: JP1.3 (B); also elsewhere on the board
~RESET: U18.34 (~RES); also elsewhere on the board
~VIA_CS: U18.23 (~CS2); also elsewhere on the board

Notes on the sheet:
Address range: $8210 to $821F on CPU1 Other VIA's can be placed at $822x, $824x, $828x, and $830x. A4 must not be 1 in the other addresses or a bus conflict will occur.

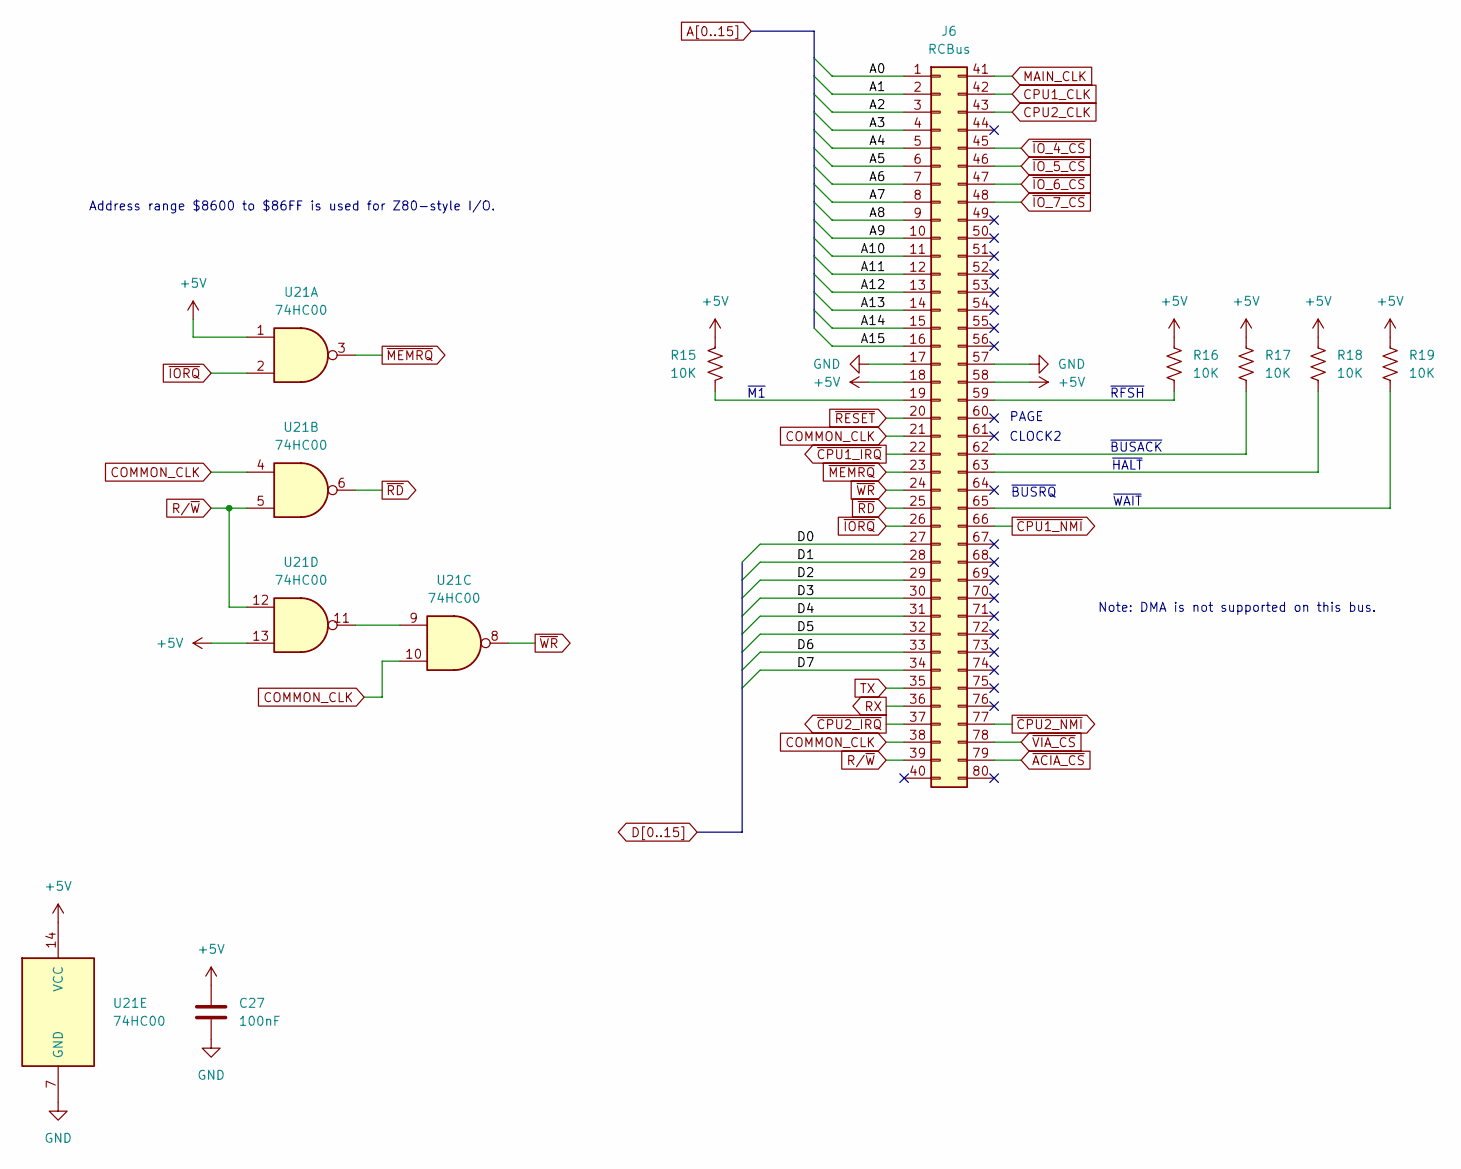
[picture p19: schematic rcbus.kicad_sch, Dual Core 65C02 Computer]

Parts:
C27: 100nF; C_Disc_D5.0mm_W2.5mm_P5.00mm
J6: RCBus; RCBus_PinSocket_2x40_P2.54mm_Vertical_DC
R15, R16, R17, R18, R19: 10K; R_Axial_DIN0207_L6.3mm_D2.5mm_P10.16mm_Horizontal
U21: 74HC00; DIP-14_W7.62mm_Socket

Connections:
+5V: C27.1, J6.18, J6.58, R15.1, R16.1, R17.1, R18.1, R19.1, U21.1, U21.13, U21.14 (VCC); also elsewhere on the board
A0: J6.1; also elsewhere on the board
A1: J6.2; also elsewhere on the board
A2: J6.3; also elsewhere on the board
A3: J6.4; also elsewhere on the board
A4: J6.5; also elsewhere on the board
A5: J6.6; also elsewhere on the board
A6: J6.7; also elsewhere on the board
A7: J6.8; also elsewhere on the board
A8: J6.9; also elsewhere on the board
A9: J6.10; also elsewhere on the board
A10: J6.11; also elsewhere on the board
A11: J6.12; also elsewhere on the board
A12: J6.13; also elsewhere on the board
A13: J6.14; also elsewhere on the board
A14: J6.15; also elsewhere on the board
A15: J6.16; also elsewhere on the board
COMMON_CLK: J6.21, J6.38, U21.4, U21.10; also elsewhere on the board
CPU1_CLK: J6.42; also elsewhere on the board
CPU2_CLK: J6.43; also elsewhere on the board
D0: J6.27; also elsewhere on the board
D1: J6.28; also elsewhere on the board
D2: J6.29; also elsewhere on the board
D3: J6.30; also elsewhere on the board
D4: J6.31; also elsewhere on the board
D5: J6.32; also elsewhere on the board
D6: J6.33; also elsewhere on the board
D7: J6.34; also elsewhere on the board
GND: C27.2, J6.17, J6.57, U21.7 (GND); also elsewhere on the board
MAIN_CLK: J6.41; also elsewhere on the board
unnamed: J6.19, R15.2
unnamed: J6.59, R16.2
unnamed: J6.62, R17.2
unnamed: J6.63, R18.2
unnamed: J6.65, R19.2
unnamed: U21.9, U21.11
RX: J6.36; also elsewhere on the board
R/~W: J6.39, U21.5, U21.12; also elsewhere on the board
TX: J6.35; also elsewhere on the board
~ACIA_CS: J6.79; also elsewhere on the board
~CPU1_IRQ: J6.22; also elsewhere on the board
~CPU1_NMI: J6.66; also elsewhere on the board
~CPU2_IRQ: J6.37; also elsewhere on the board
~CPU2_NMI: J6.77; also elsewhere on the board
~IORQ: J6.26, U21.2; also elsewhere on the board
~IO_4_CS: J6.45; also elsewhere on the board
~IO_5_CS: J6.46; also elsewhere on the board
~IO_6_CS: J6.47; also elsewhere on the board
~IO_7_CS: J6.48; also elsewhere on the board
~MEMRQ: J6.23, U21.3
~RD: J6.25, U21.6
~RESET: J6.20; also elsewhere on the board
~VIA_CS: J6.78; also elsewhere on the board
~WR: J6.24, U21.8

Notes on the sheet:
~{RFSH}
~{M1}
~{WAIT}
PAGE
~{BUSRQ}
~{HALT}
CLOCK2
Address range $8600 to $86FF is used for Z80-style I/O.
~{BUSACK}
Note: DMA is not supported on this bus.

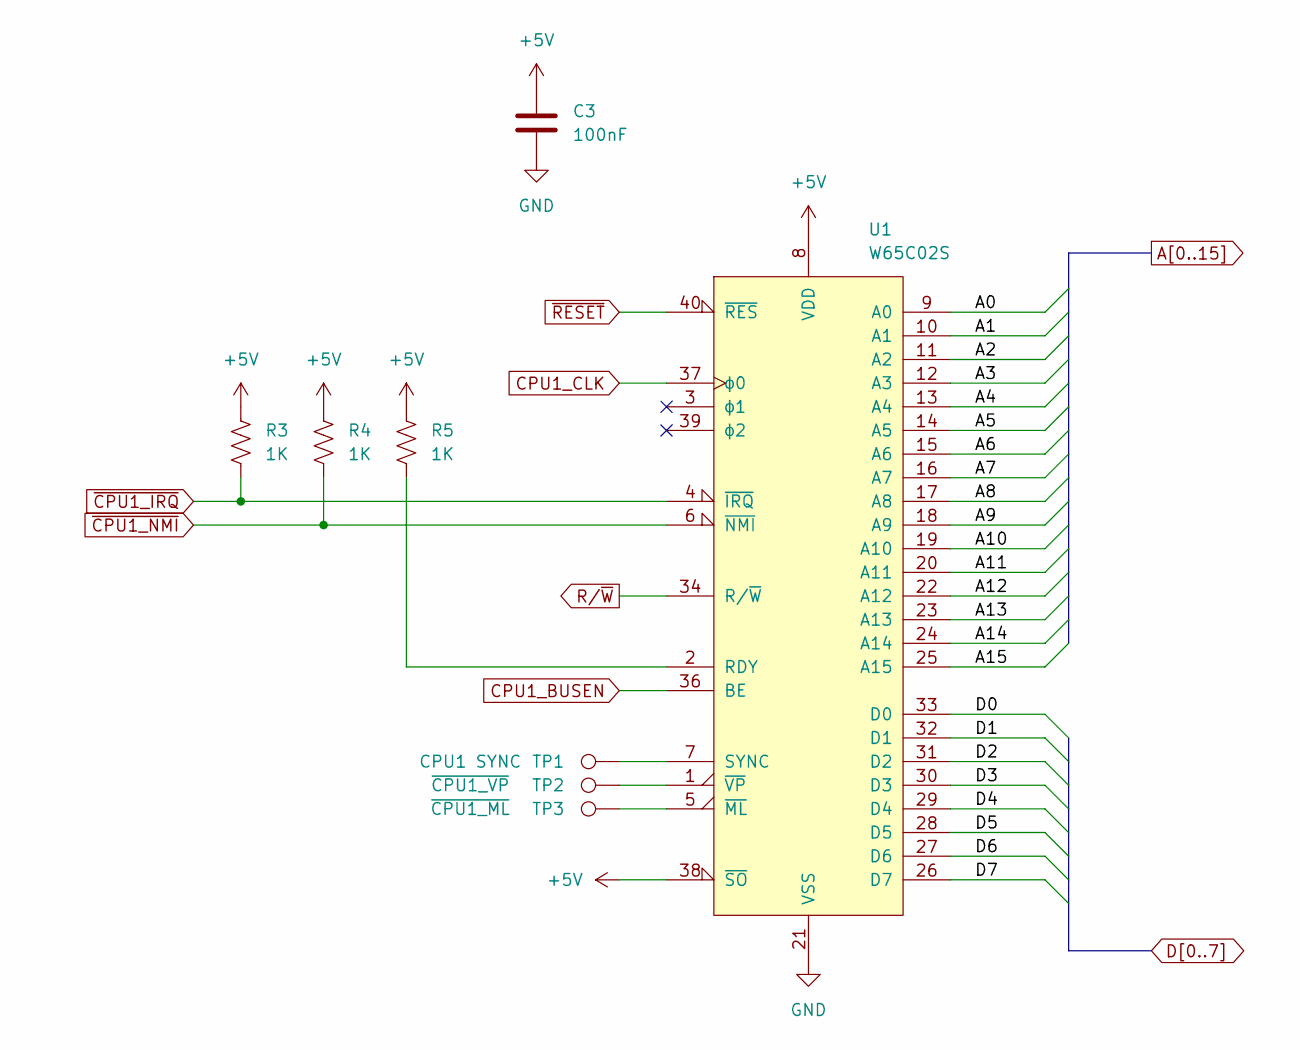
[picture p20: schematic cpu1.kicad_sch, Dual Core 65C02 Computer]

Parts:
C3: 100nF; C_Disc_D5.0mm_W2.5mm_P5.00mm
R3, R4, R5: 1K; R_Axial_DIN0207_L6.3mm_D2.5mm_P10.16mm_Horizontal
TP1: CPU1 SYNC; TestPoint_Pad_D1.5mm
TP2: ~{CPU1_VP}; TestPoint_Pad_D1.5mm
TP3: ~{CPU1_ML}; TestPoint_Pad_D1.5mm
U1: W65C02S; DIP-40_W15.24mm_Socket

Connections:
+5V: C3.1, R3.1, R4.1, R5.1, U1.8 (VDD), U1.38 (~SO); also elsewhere on the board
A0: U1.9 (A0); also elsewhere on the board
A1: U1.10 (A1); also elsewhere on the board
A2: U1.11 (A2); also elsewhere on the board
A3: U1.12 (A3); also elsewhere on the board
A4: U1.13 (A4); also elsewhere on the board
A5: U1.14 (A5); also elsewhere on the board
A6: U1.15 (A6); also elsewhere on the board
A7: U1.16 (A7); also elsewhere on the board
A8: U1.17 (A8); also elsewhere on the board
A9: U1.18 (A9); also elsewhere on the board
A10: U1.19 (A10); also elsewhere on the board
A11: U1.20 (A11); also elsewhere on the board
A12: U1.22 (A12); also elsewhere on the board
A13: U1.23 (A13); also elsewhere on the board
A14: U1.24 (A14); also elsewhere on the board
A15: U1.25 (A15); also elsewhere on the board
CPU1_BUSEN: U1.36 (BE); also elsewhere on the board
CPU1_CLK: U1.37 (ϕ0); also elsewhere on the board
D0: U1.33 (D0); also elsewhere on the board
D1: U1.32 (D1); also elsewhere on the board
D2: U1.31 (D2); also elsewhere on the board
D3: U1.30 (D3); also elsewhere on the board
D4: U1.29 (D4); also elsewhere on the board
D5: U1.28 (D5); also elsewhere on the board
D6: U1.27 (D6); also elsewhere on the board
D7: U1.26 (D7); also elsewhere on the board
GND: C3.2, U1.21 (VSS); also elsewhere on the board
unnamed: R5.2, U1.2 (RDY)
unnamed: TP1.1, U1.7 (SYNC)
unnamed: TP3.1, U1.5 (~ML)
unnamed: TP2.1, U1.1 (~VP)
R/~W: U1.34 (R/~W); also elsewhere on the board
~CPU1_IRQ: R3.2, U1.4 (~IRQ); also elsewhere on the board
~CPU1_NMI: R4.2, U1.6 (~NMI); also elsewhere on the board
~RESET: U1.40 (~RES); also elsewhere on the board

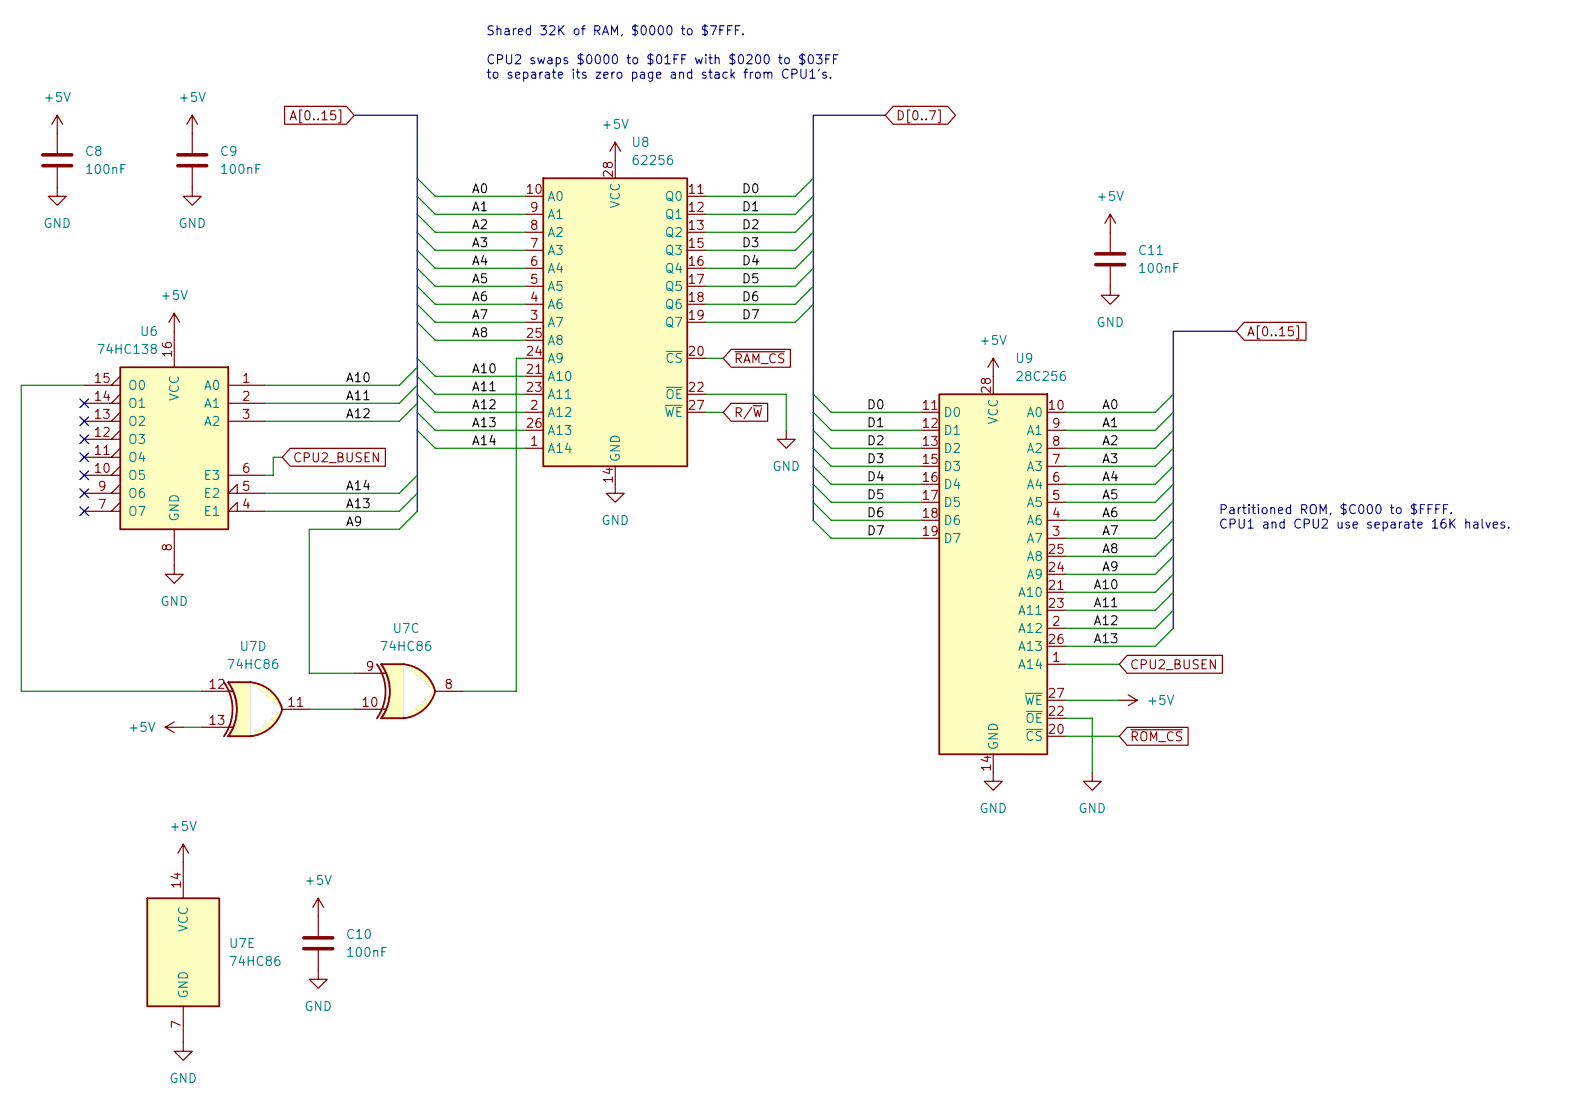
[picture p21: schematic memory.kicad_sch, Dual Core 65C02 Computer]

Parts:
C8, C9, C10, C11: 100nF; C_Disc_D5.0mm_W2.5mm_P5.00mm
U6: 74HC138; DIP-16_W7.62mm_Socket
U7: 74HC86; DIP-14_W7.62mm_Socket
U8: 62256; DIP-28_W15.24mm_Socket
U9: 28C256; DIP_Socket-28_W11.9_W12.7_W15.24_W17.78_W18.5_3M_228-1277-0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

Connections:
+5V: C8.1, C9.1, C10.1, C11.1, U6.16 (VCC), U7.13, U7.14 (VCC), U8.28 (VCC), U9.27 (~WE), U9.28 (VCC); also elsewhere on the board
A0: U8.10 (A0), U9.10 (A0); also elsewhere on the board
A1: U8.9 (A1), U9.9 (A1); also elsewhere on the board
A2: U8.8 (A2), U9.8 (A2); also elsewhere on the board
A3: U8.7 (A3), U9.7 (A3); also elsewhere on the board
A4: U8.6 (A4), U9.6 (A4); also elsewhere on the board
A5: U8.5 (A5), U9.5 (A5); also elsewhere on the board
A6: U8.4 (A6), U9.4 (A6); also elsewhere on the board
A7: U8.3 (A7), U9.3 (A7); also elsewhere on the board
A8: U8.25 (A8), U9.25 (A8); also elsewhere on the board
A9: U7.9, U9.24 (A9); also elsewhere on the board
A10: U6.1 (A0), U8.21 (A10), U9.21 (A10); also elsewhere on the board
A11: U6.2 (A1), U8.23 (A11), U9.23 (A11); also elsewhere on the board
A12: U6.3 (A2), U8.2 (A12), U9.2 (A12); also elsewhere on the board
A13: U6.4 (E1), U8.26 (A13), U9.26 (A13); also elsewhere on the board
A14: U6.5 (E2), U8.1 (A14); also elsewhere on the board
CPU2_BUSEN: U6.6 (E3), U9.1 (A14); also elsewhere on the board
D0: U8.11 (Q0), U9.11 (D0); also elsewhere on the board
D1: U8.12 (Q1), U9.12 (D1); also elsewhere on the board
D2: U8.13 (Q2), U9.13 (D2); also elsewhere on the board
D3: U8.15 (Q3), U9.15 (D3); also elsewhere on the board
D4: U8.16 (Q4), U9.16 (D4); also elsewhere on the board
D5: U8.17 (Q5), U9.17 (D5); also elsewhere on the board
D6: U8.18 (Q6), U9.18 (D6); also elsewhere on the board
D7: U8.19 (Q7), U9.19 (D7); also elsewhere on the board
GND: C8.2, C9.2, C10.2, C11.2, U6.8 (GND), U7.7 (GND), U8.14 (GND), U8.22 (~OE), U9.14 (GND), U9.22 (~OE); also elsewhere on the board
unnamed: U6.15 (O0), U7.12
unnamed: U7.10, U7.11
unnamed: U7.8, U8.24 (A9)
R/~W: U8.27 (~WE); also elsewhere on the board
~RAM_CS: U8.20 (~CS); also elsewhere on the board
~ROM_CS: U9.20 (~CS); also elsewhere on the board

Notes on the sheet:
Shared 32K of RAM, $0000 to $7FFF. CPU2 swaps $0000 to $01FF with $0200 to $03FF to separate its zero page and stack from CPU1's.
Partitioned ROM, $C000 to $FFFF. CPU1 and CPU2 use separate 16K halves.

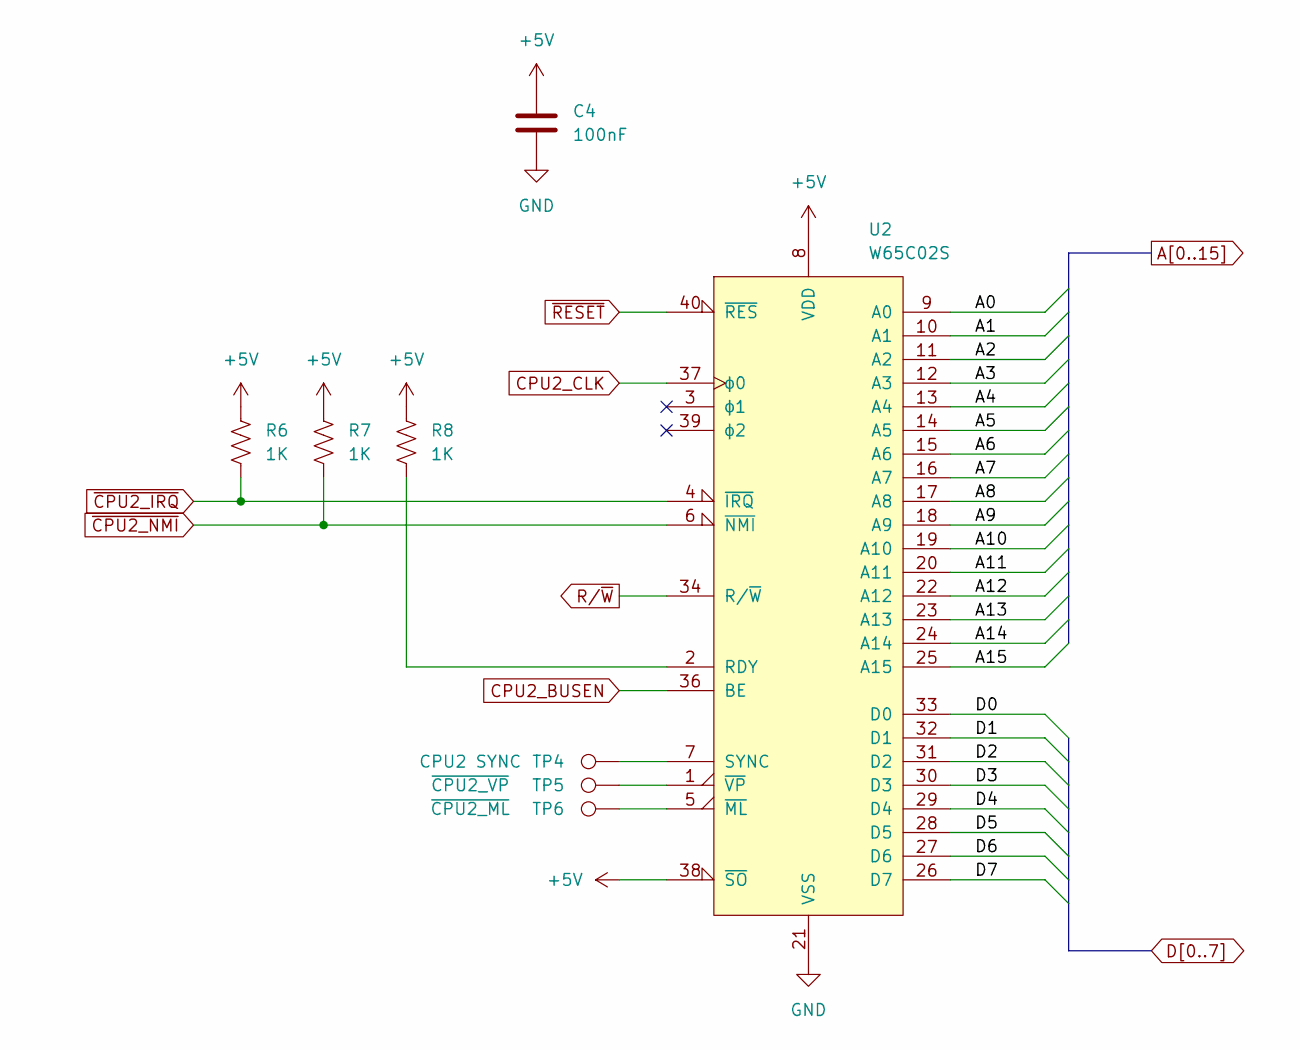
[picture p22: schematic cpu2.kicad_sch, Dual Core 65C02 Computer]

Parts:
C4: 100nF; C_Disc_D5.0mm_W2.5mm_P5.00mm
R6, R7, R8: 1K; R_Axial_DIN0207_L6.3mm_D2.5mm_P10.16mm_Horizontal
TP4: CPU2 SYNC; TestPoint_Pad_D1.5mm
TP5: ~{CPU2_VP}; TestPoint_Pad_D1.5mm
TP6: ~{CPU2_ML}; TestPoint_Pad_D1.5mm
U2: W65C02S; DIP-40_W15.24mm_Socket

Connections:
+5V: C4.1, R6.1, R7.1, R8.1, U2.8 (VDD), U2.38 (~SO); also elsewhere on the board
A0: U2.9 (A0); also elsewhere on the board
A1: U2.10 (A1); also elsewhere on the board
A2: U2.11 (A2); also elsewhere on the board
A3: U2.12 (A3); also elsewhere on the board
A4: U2.13 (A4); also elsewhere on the board
A5: U2.14 (A5); also elsewhere on the board
A6: U2.15 (A6); also elsewhere on the board
A7: U2.16 (A7); also elsewhere on the board
A8: U2.17 (A8); also elsewhere on the board
A9: U2.18 (A9); also elsewhere on the board
A10: U2.19 (A10); also elsewhere on the board
A11: U2.20 (A11); also elsewhere on the board
A12: U2.22 (A12); also elsewhere on the board
A13: U2.23 (A13); also elsewhere on the board
A14: U2.24 (A14); also elsewhere on the board
A15: U2.25 (A15); also elsewhere on the board
CPU2_BUSEN: U2.36 (BE); also elsewhere on the board
CPU2_CLK: U2.37 (ϕ0); also elsewhere on the board
D0: U2.33 (D0); also elsewhere on the board
D1: U2.32 (D1); also elsewhere on the board
D2: U2.31 (D2); also elsewhere on the board
D3: U2.30 (D3); also elsewhere on the board
D4: U2.29 (D4); also elsewhere on the board
D5: U2.28 (D5); also elsewhere on the board
D6: U2.27 (D6); also elsewhere on the board
D7: U2.26 (D7); also elsewhere on the board
GND: C4.2, U2.21 (VSS); also elsewhere on the board
unnamed: R8.2, U2.2 (RDY)
unnamed: TP4.1, U2.7 (SYNC)
unnamed: TP6.1, U2.5 (~ML)
unnamed: TP5.1, U2.1 (~VP)
R/~W: U2.34 (R/~W); also elsewhere on the board
~CPU2_IRQ: R6.2, U2.4 (~IRQ); also elsewhere on the board
~CPU2_NMI: R7.2, U2.6 (~NMI); also elsewhere on the board
~RESET: U2.40 (~RES); also elsewhere on the board

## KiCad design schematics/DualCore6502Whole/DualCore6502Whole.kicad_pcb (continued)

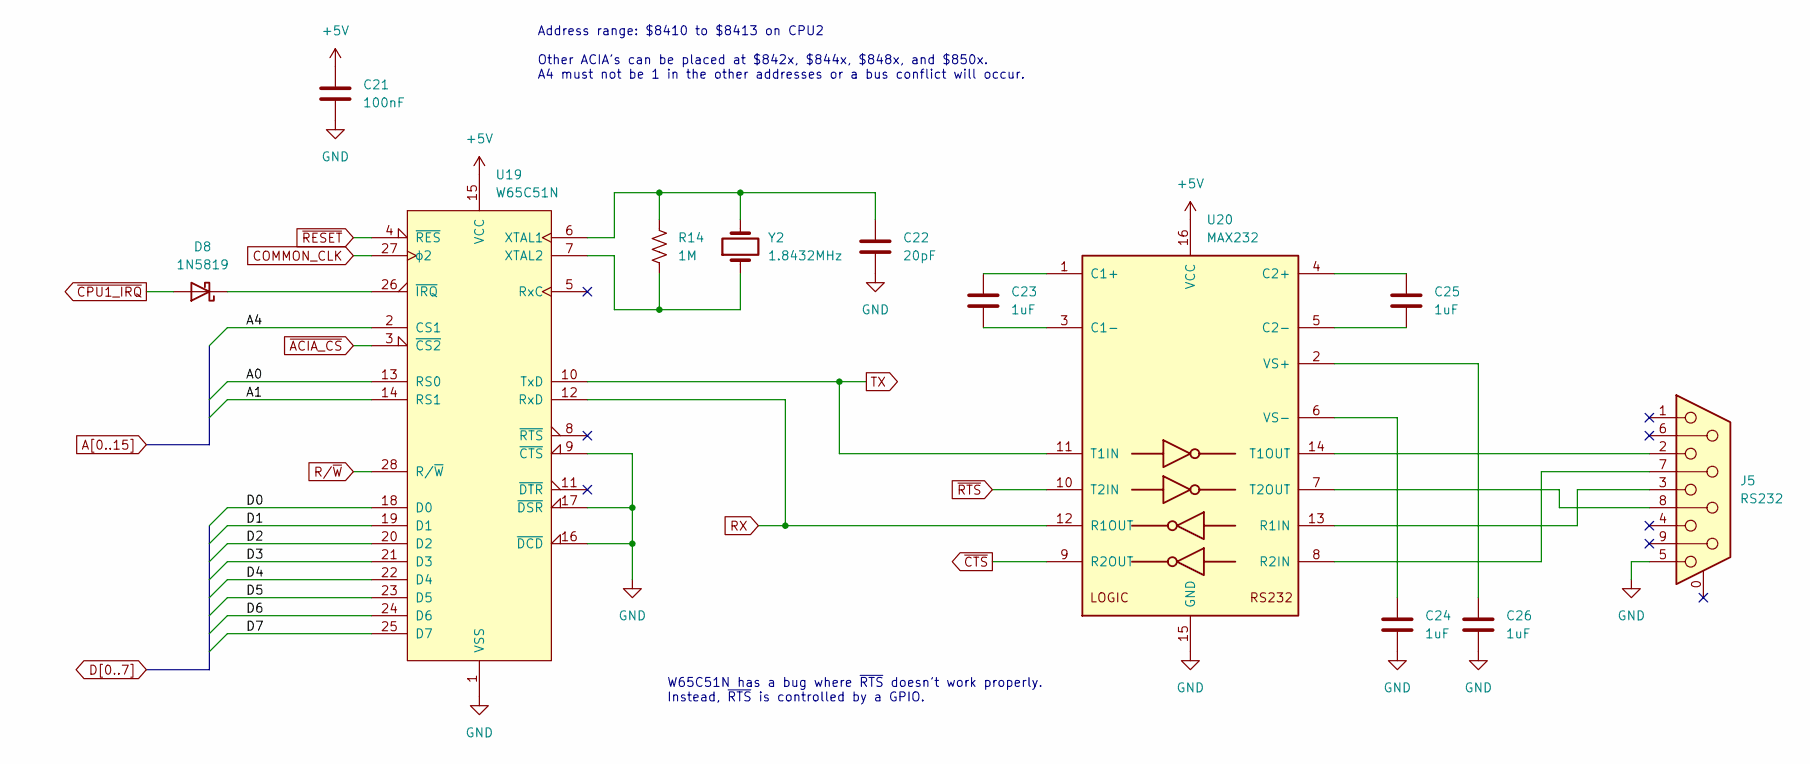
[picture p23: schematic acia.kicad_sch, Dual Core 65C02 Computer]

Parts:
C21: 100nF; C_Disc_D5.0mm_W2.5mm_P5.00mm
C22: 20pF; C_Disc_D5.0mm_W2.5mm_P5.00mm
C23, C24, C25, C26: 1uF; C_Disc_D5.0mm_W2.5mm_P5.00mm
D8: 1N5819; D_DO-41_SOD81_P10.16mm_Horizontal
J5: RS232; DSUB-9_Female_Horizontal_P2.77x2.84mm_EdgePinOffset4.94mm_H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
R14: 1M; R_Axial_DIN0207_L6.3mm_D2.5mm_P10.16mm_Horizontal
U19: W65C51N; DIP-28_W15.24mm_Socket
U20: MAX232; DIP-16_W7.62mm_Socket
Y2: 1.8432MHz; Crystal_HC49-U_Vertical

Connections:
+5V: C21.1, U19.15 (VCC), U20.16 (VCC); also elsewhere on the board
A0: U19.13 (RS0); also elsewhere on the board
A1: U19.14 (RS1); also elsewhere on the board
A4: U19.2 (CS1); also elsewhere on the board
COMMON_CLK: U19.27 (ϕ2); also elsewhere on the board
D0: U19.18 (D0); also elsewhere on the board
D1: U19.19 (D1); also elsewhere on the board
D2: U19.20 (D2); also elsewhere on the board
D3: U19.21 (D3); also elsewhere on the board
D4: U19.22 (D4); also elsewhere on the board
D5: U19.23 (D5); also elsewhere on the board
D6: U19.24 (D6); also elsewhere on the board
D7: U19.25 (D7); also elsewhere on the board
GND: C21.2, C22.2, C24.2, C26.2, J5.5, U19.1 (VSS), U19.9 (~CTS), U19.16 (~DCD), U19.17 (~DSR), U20.15 (GND); also elsewhere on the board
unnamed: D8.1 (K), U19.26 (~IRQ)
unnamed: C22.1, R14.1, U19.6 (XTAL1), Y2.2
unnamed: R14.2, U19.7 (XTAL2), Y2.1
unnamed: C23.1, U20.1 (C1+)
unnamed: C23.2, U20.3 (C1-)
unnamed: C25.1, U20.4 (C2+)
unnamed: C25.2, U20.5 (C2-)
unnamed: J5.3, U20.13 (R1IN)
unnamed: J5.7, U20.8 (R2IN)
unnamed: J5.2, U20.14 (T1OUT)
unnamed: J5.8, U20.7 (T2OUT)
unnamed: C26.1, U20.2 (VS+)
unnamed: C24.1, U20.6 (VS-)
RX: U19.12 (RxD), U20.12 (R1OUT); also elsewhere on the board
R/~W: U19.28 (R/~W); also elsewhere on the board
TX: U19.10 (TxD), U20.11 (T1IN); also elsewhere on the board
~ACIA_CS: U19.3 (~CS2); also elsewhere on the board
~CPU1_IRQ: D8.2 (A); also elsewhere on the board
~CTS: U20.9 (R2OUT); also elsewhere on the board
~RESET: U19.4 (~RES); also elsewhere on the board
~RTS: U20.10 (T2IN); also elsewhere on the board

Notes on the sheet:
W65C51N has a bug where ~{RTS} doesn't work properly. Instead, ~{RTS} is controlled by a GPIO.
Address range: $8410 to $8413 on CPU2 Other ACIA's can be placed at $842x, $844x, $848x, and $850x. A4 must not be 1 in the other addresses or a bus conflict will occur.

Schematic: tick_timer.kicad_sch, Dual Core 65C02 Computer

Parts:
C28: 10nF; C_Disc_D5.0mm_W2.5mm_P5.00mm
C29: 100nF; C_Disc_D5.0mm_W2.5mm_P5.00mm
JP2: NMI1; PinHeader_1x02_P2.54mm_Vertical
JP3: NMI2; PinHeader_1x02_P2.54mm_Vertical
R20: 5K6; R_Axial_DIN0207_L6.3mm_D2.5mm_P10.16mm_Horizontal
R21: 2K2; R_Axial_DIN0207_L6.3mm_D2.5mm_P10.16mm_Horizontal
RV1: 10K; Potentiometer_Bourns_3266Y_Vertical
TP7: 1KHz; TestPoint_Pad_D1.5mm
U4: 74HC02; DIP-14_W7.62mm_Socket
U22: 7555; DIP-8_W7.62mm_Socket

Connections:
+5V: R20.1, U22.8 (VCC); also elsewhere on the board
GND: C28.2, C29.2, U4.8, U4.12, U22.1 (GND); also elsewhere on the board
unnamed: JP2.1 (A), U4.13
unnamed: JP3.1 (A), U4.10
unnamed: R21.2, RV1.2
unnamed: C28.1, U22.5 (CV)
unnamed: R20.2, R21.1, U22.7 (DIS)
unnamed: TP7.1, U4.9, U4.11, U22.3 (Q)
unnamed: C29.1, RV1.3, U22.2 (TR), U22.6 (THR)
~CPU1_NMI: JP2.2 (B); also elsewhere on the board
~CPU2_NMI: JP3.2 (B); also elsewhere on the board
~RESET: U22.4 (R); also elsewhere on the board

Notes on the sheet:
Provides a 1ms signal to the CPU's for timing events when RV1 = 2K2
Invert so ~{CPUn_NMI} is pulled high during reset.

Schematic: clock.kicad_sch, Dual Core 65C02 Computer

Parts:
C5, C6, C7: 100nF; C_Disc_D5.0mm_W2.5mm_P5.00mm
U3: 74HC32; DIP-14_W7.62mm_Socket
U4: 74HC02; DIP-14_W7.62mm_Socket
U5: 74HC4017; DIP-16_W7.62mm_Socket
Y1: 12MHz; Oscillator_DIP-14

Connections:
+5V: C5.1, C6.1, C7.1, U3.14 (VCC), U4.14 (VCC), U5.16 (VDD), Y1.14 (Vcc); also elsewhere on the board
BUSEN_RESET: U4.2, U5.7 (Q3)
BUSEN_SET: U4.6, U5.3 (Q0)
COMMON_CLK: U3.11; also elsewhere on the board
CPU1_BUSEN: U4.1, U4.5; also elsewhere on the board
CPU1_CLK: U3.3; also elsewhere on the board
CPU1_CLK_RAW: U3.1, U3.13, U5.2 (Q1)
CPU2_BUSEN: U4.3, U4.4; also elsewhere on the board
CPU2_CLK: U3.8; also elsewhere on the board
CPU2_CLK_RAW: U3.10, U3.12, U5.10 (Q4)
GND: C5.2, C6.2, C7.2, U3.2, U3.4, U3.5, U3.7 (GND), U3.9, U4.7 (GND), U5.8 (VSS), U5.13 (CKEN), Y1.7 (GND); also elsewhere on the board
MAIN_CLK: U5.14 (CLK), Y1.8 (OUT); also elsewhere on the board
unnamed: U5.5 (Q6), U5.15 (Reset)

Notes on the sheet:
Raw CPU1_CLK and CPU2_CLK are delayed by one gate delay to match timing with COMMON_CLK.
MAIN_CLK
CPU2_CLK
COMMON_CLK
CPU2_BUSEN
MAIN_CLK (12MHz) is divided by 6 to create CPU1_CLK and CPU2_CLK (2MHz). Also divided by 6 to generate bus enables CPU1_BUSEN and CPU2_BUSEN. CPU1 can access the common bus only when CPU1_BUSEN is high and CPU2 can access the common bus only when CPU2_BUSEN is high. Bus enables are longer than cloc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
CPU1_CLK
CPU1_BUSEN

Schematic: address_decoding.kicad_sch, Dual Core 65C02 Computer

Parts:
C12, C13: 100nF; C_Disc_D5.0mm_W2.5mm_P5.00mm
U7: 74HC86; DIP-14_W7.62mm_Socket
U10: 74HC00; DIP-14_W7.62mm_Socket
U11: 74HC138; DIP-16_W7.62mm_Socket

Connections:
+5V: C12.1, C13.1, U7.2, U7.4, U10.13, U10.14 (VCC), U11.16 (VCC); also elsewhere on the board
A9: U11.1 (A0); also elsewhere on the board
A10: U11.2 (A1); also elsewhere on the board
A11: U11.3 (A2); also elsewhere on the board
A12: U11.4 (E1); also elsewhere on the board
A13: U11.5 (E2); also elsewhere on the board
A14: U7.1, U10.2; also elsewhere on the board
A15: U10.1, U10.4, U10.12; also elsewhere on the board
COMMON_CLK: U10.9; also elsewhere on the board
GND: C12.2, C13.2, U10.7 (GND), U11.8 (GND); also elsewhere on the board
IO_CS: U7.6, U11.6 (E3)
unnamed: U7.3, U10.5
unnamed: U7.5, U10.6
unnamed: U10.10, U10.11
~ACIA_CS: U11.13 (O2); also elsewhere on the board
~IORQ: U11.12 (O3); also elsewhere on the board
~IO_4_CS: U11.11 (O4); also elsewhere on the board
~IO_5_CS: U11.10 (O5); also elsewhere on the board
~IO_6_CS: U11.9 (O6); also elsewhere on the board
~IO_7_CS: U11.7 (O7); also elsewhere on the board
~MUTEX_CS: U11.15 (O0); also elsewhere on the board
~RAM_CS: U10.8; also elsewhere on the board
~ROM_CS: U10.3; also elsewhere on the board
~VIA_CS: U11.14 (O1); also elsewhere on the board

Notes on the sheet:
$8E00 - $8FFF
Memory Map: $0000 - $01FF - Zero page and stack for CPU1 $0200 - $03FF - Zero page and stack for CPU2 $0400 - $7FFF - Shared RAM $8000 - $8FFF - I/O Devices $9000 - $BFFF - Spare $C000 - $FFFF - This CPU's ROM
$8600 - $87FF
$8000 - $81FF
$8200 - $83FF
$8C00 - $8DFF
$8400 - $85FF
$8000 - $BFFF
$8800 - $89FF
$8A00 - $8BFF

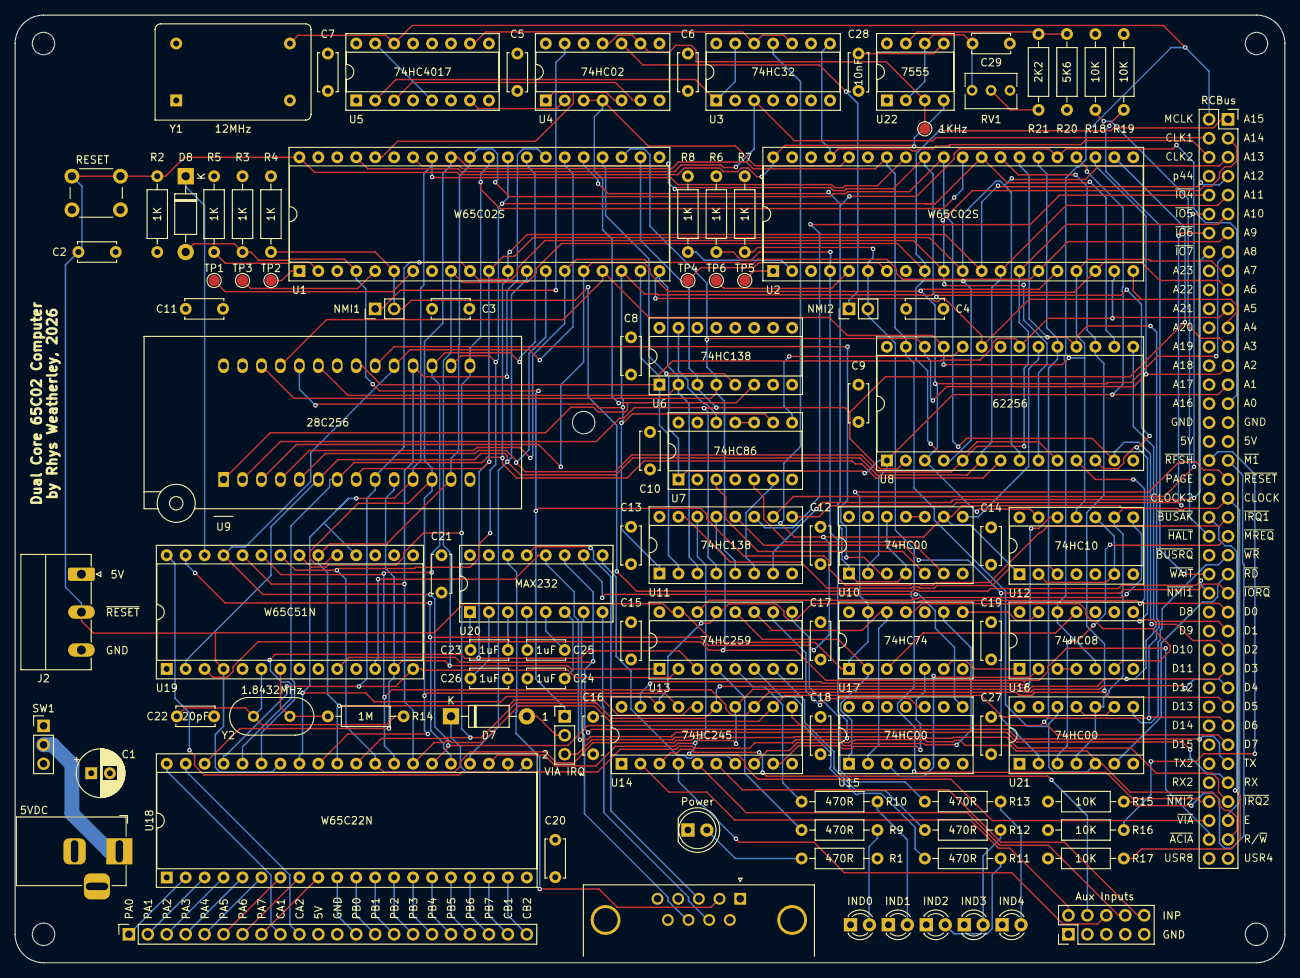
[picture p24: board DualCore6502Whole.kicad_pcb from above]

Board: 4 copper layers, 170.2 x 127.0 mm, 106 parts (0 on the bottom side), 154 nets.

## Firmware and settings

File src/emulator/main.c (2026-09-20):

/*
 * Copyright (C) 2026 Rhys Weatherley
 *
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
 * THE SOFTWARE IS PROVIDED "AS IS", WITHOUT WARRANTY OF ANY KIND, EXPRESS
 * OR IMPLIED, INCLUDING BUT NOT LIMITED TO THE WARRANTIES OF MERCHANTABILITY,
 * FITNESS FOR A PARTICULAR PURPOSE AND NONINFRINGEMENT. IN NO EVENT SHALL THE
 * AUTHORS OR COPYRIGHT HOLDERS BE LIABLE FOR ANY CLAIM, DAMAGES OR OTHER
 * LIABILITY, WHETHER IN AN ACTION OF CONTRACT, TORT OR OTHERWISE, ARISING
 * FROM, OUT OF OR IN CONNECTION WITH THE SOFTWARE OR THE USE OR OTHER
 * DEALINGS IN THE SOFTWARE.
 */

#include "emul6502.h"
#include "emulio.h"
#include <stdio.h>
#include <stdlib.h>
#include <string.h>
#include <signal.h>
#include <getopt.h>
#include <time.h>

#define short_options "thc"
static struct option long_options[] = {
    {"tty",             no_argument,        0,  't'},
    {"cycle-counter",   no_argument,        0,  'c'},
    {"help",            no_argument,        0,  '?'},
    {0,                 0,                  0,    0},
};

static void usage(const char *progname);

static emul6502_mem_t mem;  /* Shared memory */
static emul6502_t emul1;    /* Emulator for CPU1 */
static emul6502_t emul2;    /* Emulator for CPU2 */

int main(int argc, char *argv[])
{
    const char *progname = argv[0];
    const char *rom_file = NULL;
    struct timespec now, then;
    int64_t ns;

    /* Initialize the emulator */
    emul6502_init(&emul1, &mem, 1);
    emul6502_init(&emul2, &mem, 2);

    /* Parse the command-line options */
    for (;;) {
        int opt = getopt_long(argc, argv, short_options, long_options, 0);
        if (opt < 0)
            break;
        switch (opt) {
        case 't':
            emul1.cls = 0;
            emul2.cls = 0;
            break;
        case 'c':
            emul1.cycle_counter = 1;
            emul2.cycle_counter = 1;
            break;
        default:
            usage(progname);
            return 1;
        }
    }
    if (optind >= argc) {
        usage(progname);
        return 1;
    }
    rom_file = argv[optind];

    /* Load the ROM file, half into each CPU */
    if (!emul6502_load_rom_file(&emul1, rom_file)) {
        perror(rom_file);
        return 1;
    }

    /* Initialise the TTY handling on CPU1 */
    emulio_tty_init(&emul1);

    /* Reset the CPU's and start runnning */
    emul6502_reset(&emul1);
    emul6502_reset(&emul2);
    if (emul1.PC < 0xC000 || emul2.PC < 0xC000 ||
            emul6502_load_byte(&emul1, emul6502_resolve_address(&emul1, emul1.PC)) == 0 ||
            emul6502_load_byte(&emul2, emul6502_resolve_address(&emul2, emul2.PC)) == 0) {
        /* PC does not look like a valid reset address */
        emulio_tty_end(&emul1);
        fprintf(stderr, "ROM file does not have a valid reset vector\n");
        return 1;
    }
    clock_gettime(CLOCK_MONOTONIC, &then);
    for (;;) {
        /* Run some instructions */
        emul6502_step(&emul1);
        emul6502_step(&emul2);

        /* If 1ms has elapsed, simulate a system tick on the NMI pins */
        clock_gettime(CLOCK_MONOTONIC, &now);
        if (now.tv_sec == then.tv_sec) {
            ns = now.tv_nsec - then.tv_nsec;
        } else {
            ns = 1000000000 - then.tv_nsec;
            ns += now.tv_nsec;
            ns += (now.tv_sec - then.tv_sec - 1) * 1000000000LL;
        }
        then = now;
        if (ns >= 1000000) {
            emul6502_nmi(&emul1);
            emul6502_nmi(&emul2);
        }
    }

    /* Shut the system down */
    emulio_tty_end(&emul1);
    return 0;
}

static void usage(const char *progname)
{
    fprintf(stderr, "Usage: %s [options] rom-file\n\n", progname);

    fprintf(stderr, "    --tty, -t\n");
    fprintf(stderr, "        Directly write to the TTY; do not enter alternate screen mode.\n\n");

    fprintf(stderr, "    --cycle-counter, -c\n");
    fprintf(stderr, "        Print the number of CPU cycles whenever a BRK is seen.\n\n");
}

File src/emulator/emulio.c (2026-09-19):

/*
 * Copyright (C) 2026 Rhys Weatherley
 *
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
 * THE SOFTWARE IS PROVIDED "AS IS", WITHOUT WARRANTY OF ANY KIND, EXPRESS
 * OR IMPLIED, INCLUDING BUT NOT LIMITED TO THE WARRANTIES OF MERCHANTABILITY,
 * FITNESS FOR A PARTICULAR PURPOSE AND NONINFRINGEMENT. IN NO EVENT SHALL THE
 * AUTHORS OR COPYRIGHT HOLDERS BE LIABLE FOR ANY CLAIM, DAMAGES OR OTHER
 * LIABILITY, WHETHER IN AN ACTION OF CONTRACT, TORT OR OTHERWISE, ARISING
 * FROM, OUT OF OR IN CONNECTION WITH THE SOFTWARE OR THE USE OR OTHER
 * DEALINGS IN THE SOFTWARE.
 */

#include "emulio.h"
#include <sys/ioctl.h>
#include <termios.h>
#include <unistd.h>
#include <poll.h>
#include <string.h>
#include <stdio.h>
#include <stdlib.h>
#include <errno.h>
#include <time.h>

/*
 * Locations in the I/O space between $8000 and $8FFF.
 */
#define INPUT_FLAGS 0x8080  /* Input flags */
#define RS232_RTS   0x8105  /* RTS signal to the RS-232 port */
#define MUTEX_WANT2 0x8106  /* Want the mutex on CPU2 */
#define MUTEX_WANT1 0x8107  /* Want the mutex on CPU1 */
#define ACIA_DATA   0x8410  /* ACIA data register */
#define ACIA_STATUS 0x8411  /* ACIA status register */
#define ACIA_CMD    0x8412  /* ACIA command register */
#define ACIA_CTRL   0x8413  /* ACIA control register */

/*
 * Input flags.
 */
#define FLAG_CTS    0x20    /* CTS signal from the RS-232 port */
#define FLAG_ACQ2   0x40    /* Acquired the mutex on CPU2 */
#define FLAG_ACQ1   0x80    /* Acquired the mutex on CPU1 */

/*
 * I/O flags in the emul6502_mem_t structure.
 */
#define IO_WANT1    0x0001  /* Want the mutex on CPU1 */
#define IO_WANT2    0x0002  /* Want the mutex on CPU2 */
#define IO_ACQ1     0x0004  /* Acquired the mutex on CPU1 */
#define IO_ACQ2     0x0008  /* Acquired the mutex on CPU2 */
#define IO_RTS      0x0010  /* RTS signal is raised, ACIA comms allowed */
#define IO_CTS      0x0020  /* CTS signal is lowered */

/*
 * Memory locations for the serial buffer in CPU1.
 */
#define SER_RD      0x00FC  /* Read pointer */
#define SER_WR      0x00FB  /* Write pointer */
#define SER_BUF     0x7F00  /* Serial receive buffer */

uint8_t emulio_load_byte(emul6502_t *emul, uint32_t addr)
{
    uint8_t result = 0;
    switch (addr) {
    case INPUT_FLAGS:
        if (emul->mem->io_flags & IO_ACQ1) {
            result |= FLAG_ACQ1;
        }
        if (emul->mem->io_flags & IO_ACQ2) {
            result |= FLAG_ACQ2;
        }
        if (emul->mem->io_flags & IO_CTS) {
            result |= FLAG_CTS;
        }
#if 0
        if (emul->cpu_num == 1) {
            /* Probably polling for the mutex on CPU1.  If we don't have it,
             * perform a small delay to avoid pegging the host CPU at 100% */
            if (!(emul->mem->io_flags & IO_ACQ1)) {
                usleep(1000);
            }
        } else {
            /* Same, but for CPU2 this time */
            if (!(emul->mem->io_flags & IO_ACQ2)) {
                usleep(1000);
            }
        }
#endif
        return result;

    default: break;
    }
    return 0;
}

void emulio_store_byte(emul6502_t *emul, uint32_t addr, uint8_t value)
{
    switch (addr) {
    case RS232_RTS:
        /* Raise or lower the RTS signal on the RS-232 port */
        if (value & 0x01) {
            emul->mem->io_flags |= IO_RTS;
        } else {
            emul->mem->io_flags &= ~IO_RTS;
        }
        break;

    case MUTEX_WANT1:
        /* CPU1 either wants the mutex or is releasing the mutex */
        if (value & 0x01) {
            emul->mem->io_flags |= IO_WANT1;
            if (!(emul->mem->io_flags & IO_ACQ2)) {
                emul->mem->io_flags |= IO_ACQ1;
            }
        } else {
            emul->mem->io_flags &= ~(IO_WANT1 | IO_ACQ1);
            if (emul->mem->io_flags & IO_WANT2) {
                emul->mem->io_flags |= IO_ACQ2;
            }
        }
        break;

    case MUTEX_WANT2:
        /* CPU2 either wants the mutex or is releasing the mutex */
        if (value & 0x01) {
            emul->mem->io_flags |= IO_WANT2;
            if (!(emul->mem->io_flags & IO_ACQ1)) {
                emul->mem->io_flags |= IO_ACQ2;
            }
        } else {
            emul->mem->io_flags &= ~(IO_WANT2 | IO_ACQ2);
            if (emul->mem->io_flags & IO_WANT1) {
                emul->mem->io_flags |= IO_ACQ1;
            }
        }
        break;

    case ACIA_DATA:
        /* Write to the serial port */
        emulio_tty_out(emul, value);
        break;

    case ACIA_STATUS:
    case ACIA_CMD:
    case ACIA_CTRL:
        /* Ignore ACIA setup as we assume we're running at full speed */
        break;

    default: break;
    }
}

static inline int emulio_tty_write_str(const char *str)
{
    int len = write(1, str, strlen(str));
    tcdrain(1);
    return len;
}

static inline int emulio_tty_write_ch(char ch)
{
    int len = write(1, &ch, 1);
    tcdrain(1);
    return len;
}

static struct termios orig_tio1, orig_tio2;

void emulio_tty_init(emul6502_t *emul)
{
    struct termios tio1, tio2;
    (void)emul;
    cfmakeraw(&orig_tio1);
    cfmakeraw(&orig_tio2);
    if (tcgetattr(0, &tio1) < 0 || tcgetattr(1, &tio2) < 0) {
        fprintf(stderr, "stdin and stdout must be a tty\n");
        exit(1);
    }
    orig_tio1 = tio1;
    orig_tio2 = tio2;
    cfmakeraw(&tio1);
    cfmakeraw(&tio2);
    tcsetattr(0, TCSANOW, &tio1);
    tcsetattr(1, TCSANOW, &tio2);

    /* Do we need to clear the screen at startup? */
    if (emul->cls) {
        /* Enter the alternate screen mode in xterm */
        emulio_tty_write_str("\x1B[?1047h");

        /* Set normal text mode by default and clear the screen */
        emulio_tty_write_str("\x1B[m\x1B[H\x1B[J");
    }
}

void emulio_tty_end(emul6502_t *emul)
{
    /* Return to normal text mode on shutdown */
    emulio_tty_write_str("\x1B[m");
    if (emul->cls) {
        /* Exit from the alternate screen mode */
        emulio_tty_write_str("\x1B[?1047l");
    }
    tcsetattr(0, TCSANOW, &orig_tio1);
    tcsetattr(1, TCSANOW, &orig_tio2);
}

void emulio_tty_out(emul6502_t *emul, uint8_t ch)
{
    (void)emul;
    /* Determine what to do with the character.  The only special
     * one we need to handle is CTRL-L / 0x0C for "clear screen". */
    if (ch == 0x0C)
        emulio_tty_write_str("\x1B[H\x1B[J");
    else
        emulio_tty_write_ch((char)ch);
}
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

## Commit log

2026-08-30 Schematic basics
    [DualCore6502Whole.kicad_pcb, DualCore6502Whole.kicad_sch, acia.kicad_sch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]
2026-08-30 Remove the need to multiplex the control lines
    [DualCore6502Whole.kicad_pcb, acia.kicad_sch, address_decoding.kicad_sch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]
2026-09-02 Add simpler I/O outputs as an alternative to the VIA
    [acia.kicad_sch, address_decoding.kicad_sch, clock.kicad_sch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]
2026-09-09 Update the schematic
    [DualCore6502Whole.kicad_pcb, DualCore6502Whole.kicad_sch, acia.kicad_sch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]
2026-09-09 LED blink and chase examples
2026-09-11 Update schematic and add 1ms NMI tick
    [DualCore6502Whole.kicad_sch, acia.kicad_sch, address_decoding.kicad_sch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]
2026-09-16 Basic PCB layout
    [DualCore6502Whole.kicad_pcb, DualCore6502Whole.kicad_sch, acia.kicad_sch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]
2026-09-16 Power planes
    [DualCore6502Whole.kicad_pcb]
2026-09-16 Route the PCB
    [DualCore6502Whole.kicad_pcb]
2026-09-16 Generate Gerber files
    [DualCore6502Whole-B_Cu.gbl, DualCore6502Whole-B_Mask.gbs, DualCore6502Whole-B_Paste.gbp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]
2026-09-19 Update the PDF of the schematic
2026-09-30 Fix a comment in the schematics
    [clock.kicad_sch]
2026-09-30 Update README with an image of the PCB
2026-09-30 Link to the shared design on PCBway
